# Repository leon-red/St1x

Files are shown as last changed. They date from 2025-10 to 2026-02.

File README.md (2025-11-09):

# St1x
 - S: STM32F103CBT6
 - T: T系列烙铁头
 - 1x: 12 & 13 & 16
### 基于SMT32F103自动调温烙铁, 使用T12 & T13 & T16 烙铁头实现
***
# 非常感谢以下开源的作者与项目
- 项目参考：[Eddddddddy](https://github.com/Eddddddddy/T12-PD-SolderingPen)
- AI编码助手：[北京引力弹弓科技有限公司](https://www.trae.cn/)
- OLED驱动： [U8G2](https://github.com/olikraus/u8g2) 库, 具体使用方法参考 [U8G2官方WiKi](https://github.com/olikraus/u8g2)
- 下载&调试工具： [PowerWriter PWLINK2](https://item.taobao.com/item.htm?id=675067753017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)
- 开发环境:
  - [Clion 2023.3.6](https://www.jetbrains.com/zh-cn/clion/download/other.html)
  - [STM32CulbMX6.15.0](https://www.st.com.cn/content/st_com/zh/stm32cubemx.html)
  - [openocd-v0.12.0-i686-w64-mingw32](https://github.com/openocd-org/openocd)
  - [mingw64-x86_64-13.2.0-release-win32-seh-msvcrt-rt_v11-rev1](https://sourceforge.net/projects/mingw-w64/files/mingw-w64/mingw-w64-release/)
  - [arm-gnu-toolchain-13.2.Rel1-mingw-w64-i686-arm-none-eabi](https://developer.arm.com/downloads/-/arm-gnu-toolchain-downloads)

- 使用`STM32CulbMX6.15.0`打开`St1x.ioc`, 点击`GENERATE CODE`生成初始化代码, 再使用`Clion 2023.3.6`编译下载。 有时间再配合图文讲解完善操作~~~~~~
***
# 功能实现结果
## 硬件设计
  - [x] 原理图设计
  - [x] PCB设计
  - [x] 硬件电路调试
    - [x] PD快充协议触发
    - [x] 系统供电
    - [x] 按键
    - [x] 烙铁头温度控制
    - [x] 屏幕升压供电
    - [x] 工作指示灯
    - [x] 蜂鸣器提示
    - [x] 烙铁头电动势运放电路
    - [x] 加速度传感器
    - [x] 屏幕显示
***
## 外观设计
- [x] ID设计
- [x] 外壳3D设计
***
## 软件设计
- [x] O-LED_U8G2 驱动(SPI)
- [x] 界面显示
- [x] 按键控制
- [x] PID算法
- [x] ADC温度读取
- [x] USB输入电压检测
- [x] 自动温度控制
- [x] 静置检测
- [x] 烙铁头温度校准
- [ ] RGB_LED指示
- [x] WS2812B_RGB指示
- [ ] 蜂鸣器事件
***
# 图片展示


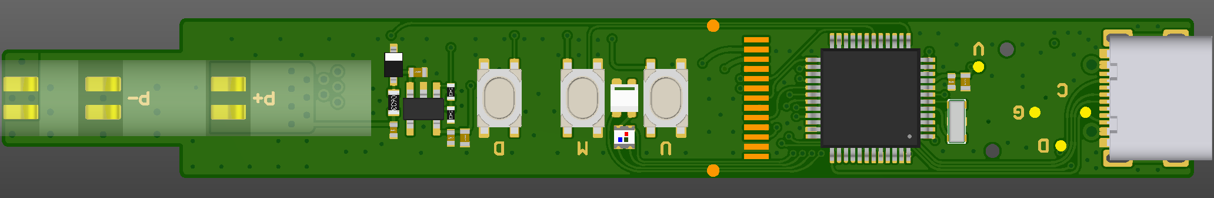
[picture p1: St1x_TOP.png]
St1x_TOP


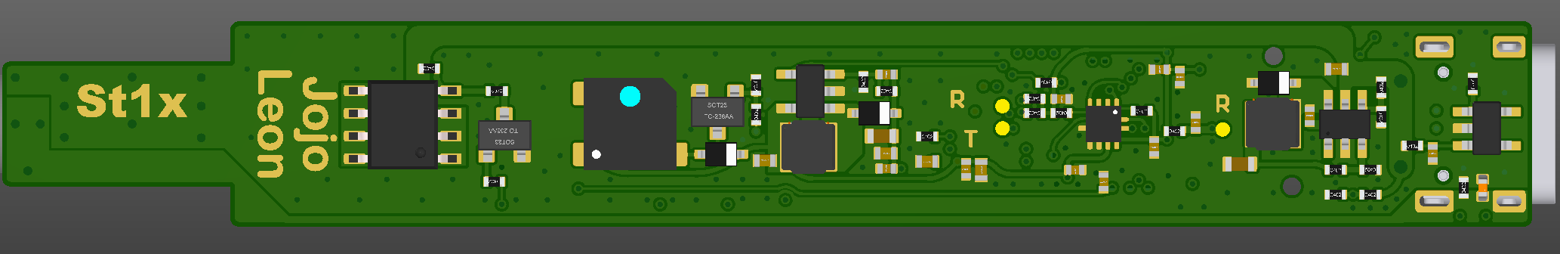
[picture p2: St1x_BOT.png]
St1x_BOT


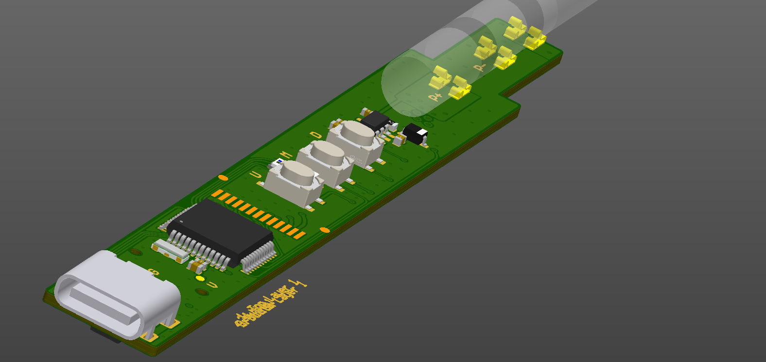
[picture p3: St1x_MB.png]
St1x_MB


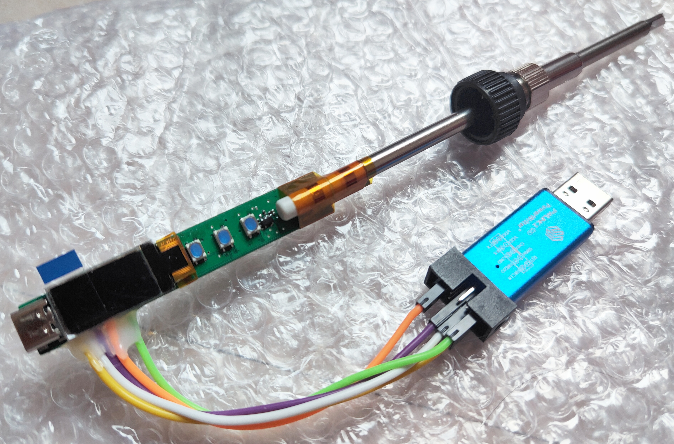
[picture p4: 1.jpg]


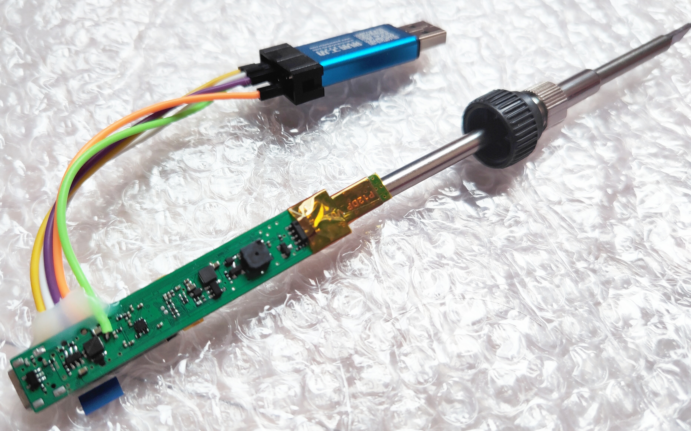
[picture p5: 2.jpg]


# 原理图
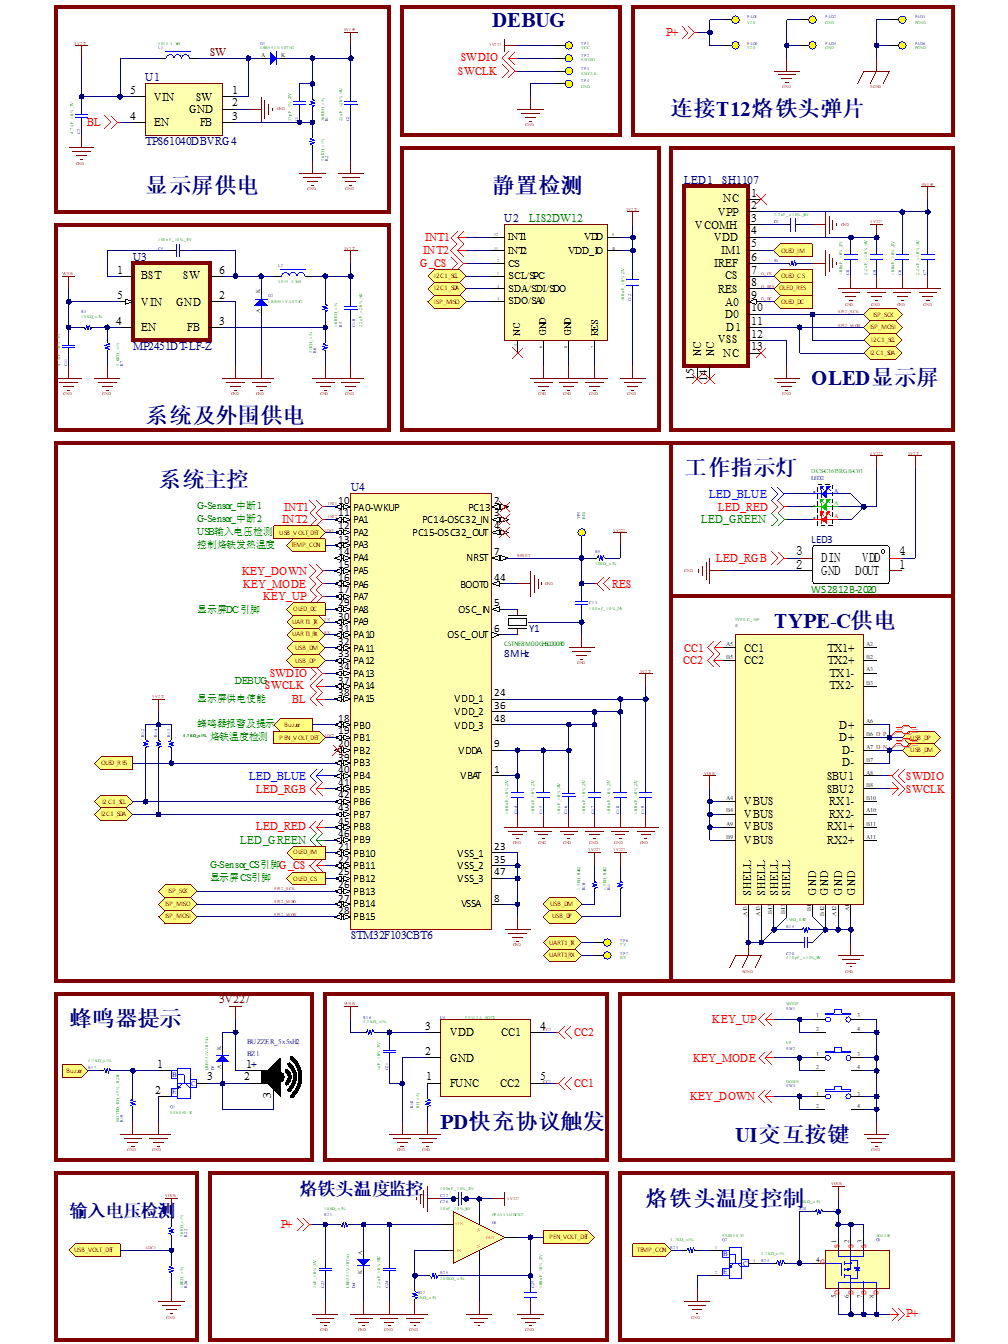
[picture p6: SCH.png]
SCH

[点击打开PDF原理图](HardwarDesign/SCH.pdf)

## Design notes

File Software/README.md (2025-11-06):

# St1x
 - S: STM32F103CBT6
 - T: T系列烙铁头
 - 1x: 12 & 13 & 16
### 基于SMT32F103自动调温烙铁, 使用T12 & T13 & T16 烙铁头实现
***
# 非常感谢以下开源的作者与项目
- 项目参考：[Eddddddddy](https://github.com/Eddddddddy/T12-PD-SolderingPen)
- AI编码助手：[北京引力弹弓科技有限公司](https://www.trae.cn/)
- OLED驱动： [U8G2](https://github.com/olikraus/u8g2) 库, 具体使用方法参考 [U8G2官方WiKi](https://github.com/olikraus/u8g2)
- 下载&调试工具： [PowerWriter PWLINK2](https://item.taobao.com/item.htm?id=675067753017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)
- 开发环境:
  - [Clion 2023.3.6](https://www.jetbrains.com/zh-cn/clion/download/other.html)
  - [STM32CulbMX6.15.0](https://www.st.com.cn/content/st_com/zh/stm32cubemx.html)
  - [openocd-v0.12.0-i686-w64-mingw32](https://github.com/openocd-org/openocd)
  - [mingw64-x86_64-13.2.0-release-win32-seh-msvcrt-rt_v11-rev1](https://sourceforge.net/projects/mingw-w64/files/mingw-w64/mingw-w64-release/)
  - [arm-gnu-toolchain-13.2.Rel1-mingw-w64-i686-arm-none-eabi](https://developer.arm.com/downloads/-/arm-gnu-toolchain-downloads)

- 使用`STM32CulbMX6.15.0`打开`St1x.ioc`, 点击`GENERATE CODE`生成初始化代码, 再使用`Clion 2023.3.6`编译下载。 有时间再配合图文讲解完善操作~~~~~~
***
# 功能实现结果
## 硬件设计
  - [x] 原理图设计
  - [x] PCB设计
  - [x] 硬件电路调试
    - [x] PD快充协议触发
    - [x] 系统供电
    - [x] 按键
    - [x] 烙铁头温度控制
    - [x] 屏幕升压供电
    - [x] 工作指示灯
    - [x] 蜂鸣器提示
    - [x] 烙铁头电动势运放电路
    - [x] 加速度传感器
    - [x] 屏幕显示
***
## 外观设计
- [x] ID设计
- [x] 外壳3D设计
***
## 软件设计
- [x] O-LED_U8G2 驱动(SPI)
- [x] 界面显示
- [x] 按键控制
- [x] PID算法
- [x] ADC温度读取
- [x] USB输入电压检测
- [x] 自动温度控制
- [ ] 静置检测
- [ ] RGB_LED指示
- [ ] WS2812B_RGB指示
- [ ] 蜂鸣器事件
***
# 图片展示














# 原理图
[SCH.pdf](..%2FHardwarDesign%2FSCH.pdf)

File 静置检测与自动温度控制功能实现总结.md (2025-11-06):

# 静置检测与自动温度控制功能实现总结

## 1. 项目目标

实现基于6轴传感器的静置检测功能，当设备静置一段时间后自动降低温度，再静置更长时间后停止加热。同时实现设备运动检测，自动恢复加热功能。

## 2. 功能实现过程

### 2.1 初始实现
- 在 [St1xStatic.c](file:///D:/Leon/OneDrive/Leon/St1x/Software/St1xDrivers/St1xStatic.c) 中实现基于LIS2DW12 6轴传感器的静置检测功能
- 设置默认参数：15分钟后降低温度至160°C，30分钟后停止加热
- 实现传感器数据读取、运动检测算法和温度控制逻辑

### 2.2 编译与链接问题修复
- 修复了函数声明和定义不匹配的问题
- 解决了静态函数访问权限问题
- 添加了必要的头文件包含和外部变量声明

### 2.3 调试信息显示
- 实现在OLED屏幕上显示调试信息，位置为X15, Y26
- 显示内容包括：加速度值、静置状态、加热状态和距离上次运动时间

### 2.4 算法优化
- 优化运动检测阈值，从300mg降低到150mg，提高检测灵敏度
- 改进传感器数据读取方式，确保每次检测都读取最新数据
- 解决时间计数器溢出问题，只在加热状态下进行静置检测

## 3. 遇到的主要问题及解决方案

### 3.1 传感器检测不灵敏
**问题**：设备无法正确进入静置状态，始终检测到运动
**解决方案**：
- 降低运动检测阈值从300mg到150mg
- 改进算法，区分传感器噪声和真实运动
- 添加误差阈值机制，过滤小幅数值跳变

### 3.2 时间计数问题
**问题**：静置时间无法正确累积，L值在0和1之间跳变
**解决方案**：
- 优化时间计算逻辑，避免因小幅跳变重置时间计数器
- 区分噪声阈值和运动检测阈值
- 确保时间累积的稳定性

### 3.3 加热控制问题
**问题**：达到设定时间后无法降低温度或停止加热
**解决方案**：
- 修复加热控制回调函数中的提前返回问题
- 确保温度设置在加热状态停止前完成
- 调整参数单位从分钟改为秒，提高调试效率

### 3.4 自动恢复问题
**问题**：设备停止加热后无法通过运动检测自动恢复
**解决方案**：
- 修改主循环调用逻辑，始终执行静置检测
- 区分自动停止和手动停止状态
- 实现手动停止标记机制，提升用户体验

## 4. 功能增强

### 4.1 手动/自动停止区分
- 添加手动停止标记，区分用户按键停止和自动停止
- 手动停止后不自动恢复加热，需要用户再次按键启动
- 自动停止后检测到运动可自动恢复加热

### 4.2 参数配置优化
- 提供默认参数配置函数，便于通过宏定义调整参数
- 统一时间单位为秒，提高调试效率
- 简化参数设置接口

### 4.3 调试信息优化
- 简化调试显示内容，只保留关键信息
- 确保调试信息与实际状态一致
- 停止加热后相关时间值归零，避免误导

## 5. 最终功能效果

1. **静置检测**：设备静置15分钟后自动降低温度至160°C，30分钟后停止加热
2. **运动检测**：设备运动时自动恢复加热状态
3. **状态区分**：自动停止后可自动恢复，手动停止后需手动启动
4. **调试显示**：在OLED屏幕指定位置显示关键状态信息
5. **安全保护**：防止用户初次上电时意外加热造成伤害

## 6. 技术要点总结

- 有效利用6轴传感器的三轴数据进行运动检测
- 实现噪声过滤算法，提高检测准确性
- 合理设计状态机，确保各状态转换正确
- 区分自动和手动操作，提升用户体验
- 优化资源使用，避免不必要的系统消耗

## 7. 经验教训

1. 传感器数据处理需要考虑噪声影响，不能直接使用原始数据
2. 时间计数逻辑需要仔细设计，避免因小幅波动影响计时准确性
3. 加热控制逻辑需要考虑回调函数的执行条件
4. 用户体验需要细致考虑，区分不同场景下的行为
5. 调试信息要准确反映系统状态，避免误导开发者或用户

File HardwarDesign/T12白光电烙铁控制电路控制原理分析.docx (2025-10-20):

# T12白光电烙铁控制电路控制原理分析

T12白光电烙铁，其烙铁头内部的加热丝与热电偶串联，两个引脚既是电源的输入线，也是热电偶信号的输出线。一般的控制电路的电路原理图一般如下:

## 电路的工作过程如下：

1、 电路中运放LM358的2脚预置了热电偶在设定的温度下的信号电压值(mV级的)，当电路上电时，LM358的3脚电压低于2脚，运放的输出端1脚输出低电平，二极管D3将另一个运放的6脚箝位为低电平，其输出端7脚会输出高电平。这个高电平经R9的电阻传递给三极管Q2，三极管将饱和，其集电极电位降低。两接到三极管C极的MOS管Q1的G极点位降低而使MOS管导通，电源经 D 极到S极开始为 T12 供电。
2、 电源为 T12 供电时，电源电压通过R5的电阻为电容器C5充电，短时间可使运放3脚的电平高于2脚，运放的1脚翻转为高电平。
3、 D3将1脚的高电平隔离，6 脚通过R7的电阻给C6的电容缓慢充电,延时到运放6脚电位高于5脚时,运放7脚输出低电平,三极管截止，Q1也截止，停止向T12供电。
4、 一旦Q1截止，停止向T12 供电。则LM358的3脚电压将迅速变为低电平。但是这个低电平实际上等于从T12 内部的热电偶通过R5的电阻传来的热电偶的信号电压。 如果此时热电偶的信号电压还低于预置的运放2脚电平,则电路状态将重复①的过程进行①→②→③→④的循环。 如果此时热电偶的信号电压已经高于预置的运放2脚电平，则意味着烙铁头温度已经达到预设值，LM358 将不会翻转，电路不会向 T12 供电。这个停电的过程一直等待运放3脚的电平再次降低到2脚的预置值以下,才开始再次翻转为T12供电。使烙铁头升温。这样的动作保持着 T12 烙铁头的恒温状态。
  a) 以上红色字体部分，是以前一般的分析资料没有明确说清楚的，它是这个控制电路能控制 T12白光温度的精髓所在。
  b) 总言之，控制电路是脉冲状态地为T12供电，脉冲宽度取决于运放5脚上R7的电阻给C6电容充电的速度。脉冲间隔很小，取决于运放3脚上C5电容器的电荷经R5的电阻再经T12的发热丝泄放的速度。在脉冲间隔期间，电路才真正检测热电偶的信号，确定脉冲供电是否应该继续进行，从而实现烙铁头的恒温。

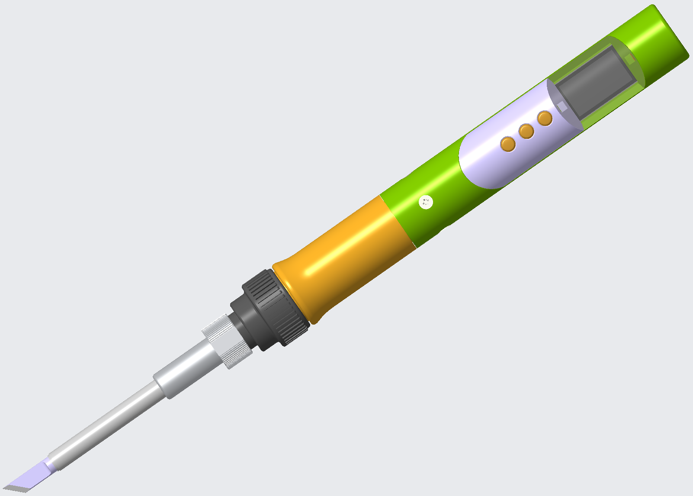
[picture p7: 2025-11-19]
HardwarDesign/Image/ST12.png

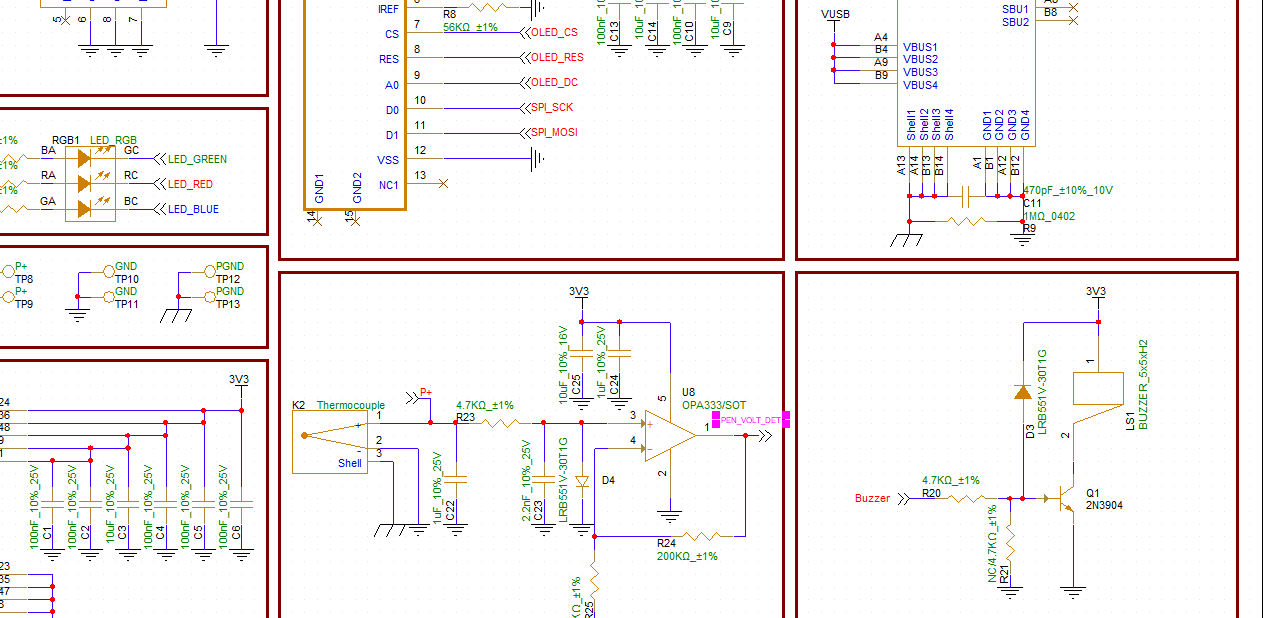
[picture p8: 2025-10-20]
HardwarDesign/Cadence/ST1X.png

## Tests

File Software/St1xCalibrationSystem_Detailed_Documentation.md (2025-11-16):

# ST1X 校准系统详细技术文档

## 1. 系统架构与设计原理

### 1.1 系统整体架构

```
┌─────────────────────────────────────────────────────────────┐
│                   主系统 (Main System)                       │
├─────────────────────────────────────────────────────────────┤
│  ┌─────────────────────────────────────────────────────┐    │
│  │             校准系统 (CalibrationSystem)            │    │
│  ├─────────────────────────────────────────────────────┤    │
│  │  ┌─────────────┐  ┌─────────────┐  ┌─────────────┐   │    │
│  │  │  状态管理   │  │  温度控制  │  │  界面显示   │   │    │
│  │  │  模块       │  │  模块      │  │  模块       │   │    │
│  │  └─────────────┘  └─────────────┘  └─────────────┘   │    │
│  │  ┌─────────────┐  ┌─────────────┐  ┌─────────────┐   │    │
│  │  │  按键处理   │  │  数据存储  │  │  电压检测   │   │    │
│  │  │  模块       │  │  模块      │  │  模块       │   │    │
│  │  └─────────────┘  └─────────────┘  └─────────────┘   │    │
│  └─────────────────────────────────────────────────────┘    │
├─────────────────────────────────────────────────────────────┤
│  ┌─────────────┐  ┌─────────────┐  ┌─────────────┐        │
│  │  PID控制    │  │  温度采集   │  │  OLED显示   │        │
│  │  系统       │  │  系统       │  │  系统       │        │
│  └─────────────┘  └─────────────┘  └─────────────┘        │
└─────────────────────────────────────────────────────────────┘
```

### 1.2 核心设计参数

**系统配置参数：**
```c
#define CALIBRATION_POINTS 9                    // 校准点数：9个
#define TEMPERATURE_TOLERANCE 5.0f              // 温度容差：±5°C
#define TEMPERATURE_STABLE_TIME 1000            // 温度稳定时间：1000ms
#define UPDATE_INTERVAL 20                       // 更新间隔：20ms
#define TEMPERATURE_ADJUST_STEP 1.0f            // 温度调整步进：1.0°C
#define KEY_DEBOUNCE_TIME 50                    // 按键去抖时间：50ms
#define CAL_KEY_LONG_PRESS_TIME 1000            // 按键长按时间：1000ms
#define LOW_VOLTAGE_DISPLAY_TIME 5000           // 电压不足显示时间：5000ms
```

**校准温度点定义：**
```c
static const float calibration_temperatures[CALIBRATION_POINTS] = {
    100.0f, 150.0f, 200.0f, 250.0f, 300.0f, 
    350.0f, 400.0f, 450.0f, 500.0f
};
```

### 1.3 数据结构设计

**校准点结构体：**
```c
typedef struct {
    uint8_t point_id;                    // 校准点ID（1-9）
    float target_temperature;           // 目标温度
    float adjusted_temperature;         // 调整后的目标温度
    float calibration_offset;           // 校准偏移量
    CalibrationPointState state;        // 当前状态
    uint32_t heating_start_time;       // 加热开始时间
    uint32_t stable_start_time;        // 稳定开始时间
    float max_temp_deviation;          // 最大温度偏差记录
    uint8_t heating_cycles;            // 加热循环次数
} CalibrationPoint;
```

**系统状态变量：**
```c
static CalibrationSystemState system_state = CAL_STATE_IDLE;
static CalibrationPoint calibration_points[CALIBRATION_POINTS];
static uint8_t current_point_index = 0;
static uint32_t last_update_time = 0;
static uint8_t save_result = 0;
static uint8_t low_voltage_state = 0;
static uint32_t low_voltage_start_time = 0;
```

## 2. 系统启动流程详细分析

### 2.1 系统初始化阶段

**调用入口：** `CalibrationSystem_Init()`

**初始化步骤：**
1. **状态变量重置**
   - `system_state = CAL_STATE_IDLE`
   - `current_point_index = 0`
   - `save_result = 0`
   - `last_update_time = 0`

2. **电压检测状态重置**
   - `low_voltage_state = 0`
   - `low_voltage_start_time = 0`

3. **校准点初始化**
   ```c
   for (int i = 0; i < CALIBRATION_POINTS; i++) {
       InitializeCalibrationPoint(i);
   }
   ```

4. **温度限制设置**
   - `calibration_temperature_limit = 500.0f`

**单个校准点初始化逻辑：**
```c
static void InitializeCalibrationPoint(uint8_t point_index) {
    CalibrationPoint* point = &calibration_points[point_index];
    
    point->point_id = point_index + 1;  // ID从1开始
    point->target_temperature = calibration_temperatures[point_index];
    point->adjusted_temperature = calibration_temperatures[point_index];
    point->calibration_offset = 0.0f;  // 初始偏移量为0
    point->state = CAL_POINT_WAITING;
    point->heating_start_time = 0;
    point->stable_start_time = 0;
    point->max_temp_deviation = 0.0f;
    point->heating_cycles = 0;
}
```

### 2.2 系统启动阶段

**调用入口：** `CalibrationSystem_Start()`

**启动条件检查：**
```c
if (system_state != CAL_STATE_IDLE) {
    return;  // 只有在空闲状态才能启动
}
```

**启动步骤详细分析：**

1. **第一个校准点设置**
   ```c
   if (CALIBRATION_POINTS > 0) {
       CalibrationPoint* first_point = &calibration_points[0];
       first_point->target_temperature = calibration_temperatures[0];
       first_point->adjusted_temperature = calibration_temperatures[0];
       
       // 设置PID目标温度
       SetPointTemperature(0, first_point->adjusted_temperature);
       
       // 显式设置目标温度变量
       extern float target_temperature;
       target_temperature = first_point->adjusted_temperature;
   }
   ```

2. **加热系统启动**
   ```c
   heating_status = 1;  // 设置加热状态为启用
   HAL_TIM_PWM_Start(&htim2, TIM_CHANNEL_2);  // 启动PWM输出
   startHeatingControlTimer();  // 启动PID控制器的定时器
   ```

3. **状态转换**
   ```c
   system_state = CAL_STATE_VOLTAGE_CHECK;
   low_voltage_start_time = HAL_GetTick();  // 记录电压检测开始时间
   ```

## 3. 电压检测阶段详细流程

### 3.1 电压检测状态处理

**处理函数：** `ProcessVoltageCheckState(uint32_t current_time)`

**检测逻辑：**
```c
// 检查电压是否足够
extern uint8_t isUSBVoltageSufficient(void);
if (isUSBVoltageSufficient()) {
    // 电压足够，进入校准运行状态
    // ... 详细处理逻辑
} else {
    // 电压不足，检查是否超过5秒显示时间
    if ((current_time - low_voltage_start_time) >= LOW_VOLTAGE_DISPLAY_TIME) {
        CalibrationSystem_Stop();  // 超过5秒，返回主界面
    }
}
```

**电压足够时的处理流程：**

1. **温度限制调整**
   ```c
   extern float max_temperature_limit;
   max_temperature_limit = 500.0f;  // 校准温度限制
   ```

2. **系统状态重置**
   ```c
   current_point_index = 0;
   save_result = 0;
   system_state = CAL_STATE_RUNNING;
   ```

3. **校准点重新初始化**
   ```c
   for (int i = 0; i < CALIBRATION_POINTS; i++) {
       InitializeCalibrationPoint(i);
   }
   ```

4. **第一个校准点启动**
   ```c
   SetPointTemperature(0, calibration_points[0].adjusted_temperature);
   calibration_points[0].state = CAL_POINT_HEATING;
   calibration_points[0].heating_start_time = current_time;
   calibration_points[0].heating_cycles = 1;
   
   // 立即将校准点温度写入目标温度变量
   extern float target_temperature;
   target_temperature = calibration_points[0].adjusted_temperature;
   ```

### 3.2 电压检测状态下的按键处理

**处理函数：** `HandleVoltageCheckKey(KeyType key)`

**按键响应逻辑：**

1. **MODE短按（确认电压正常）**
   ```c
   if (key == KEY_MODE) {
       system_state = CAL_STATE_RUNNING;
       current_point_index = 0;
       SetPointTemperature(current_point_index, calibration_points[current_point_index].adjusted_temperature);
       extern float target_temperature;
       target_temperature = calibration_points[current_point_index].adjusted_temperature;
       calibration_points[current_point_index].state = CAL_POINT_HEATING;
   }
   ```

2. **MODE长按（跳过电压检测）**
   ```c
   else if (key == KEY_MODE_LONG) {
       system_state = CAL_STATE_RUNNING;
       // ... 与短按相同的处理逻辑
   }
   ```

## 4. 校准运行阶段详细分析

### 4.1 系统更新循环

**主更新函数：** `CalibrationSystem_Update(u8g2_t *u8g2)`

**更新频率控制：**
```c
uint32_t current_time = HAL_GetTick();
if ((current_time - last_update_time) < UPDATE_INTERVAL) {
    return;  // 20ms间隔控制
}
last_update_time = current_time;
```

**更新流程：**
1. **按键扫描**
   ```c
   KeyType key = CalibrationKey_Scan();
   if (key != KEY_NONE) {
       CalibrationSystem_HandleKey(key);
   }
   ```

2. **状态处理**
   ```c
   switch (system_state) {
       case CAL_STATE_VOLTAGE_CHECK:
           ProcessVoltageCheckState(current_time);
           break;
       case CAL_STATE_RUNNING:
           ProcessCalibrationPoint(current_point_index);
           break;
       default:
           break;
   }
   ```

3. **界面绘制**
   ```c
   DrawCalibrationInterface(u8g2, current_point_index);
   ```

### 4.2 单个校准点处理状态机

**处理函数：** `ProcessCalibrationPoint(uint8_t point_index)`

#### 4.2.1 加热阶段 (CAL_POINT_HEATING)

**温度稳定性判断逻辑：**
```c
float current_temp = filtered_temperature;
float target_temp = point->adjusted_temperature;
float temp_diff = fabs(current_temp - target_temp);

// 记录最大温度偏差
if (temp_diff > point->max_temp_deviation) {
    point->max_temp_deviation = temp_diff;
}

// 检查温度是否稳定
if (temp_diff <= TEMPERATURE_TOLERANCE) {
    if (point->stable_start_time == 0) {
        point->stable_start_time = current_time;
    } else if ((current_time - point->stable_start_time) >= TEMPERATURE_STABLE_TIME) {
        point->state = CAL_POINT_STABLE;  // 进入稳定状态
    }
} else {
    point->stable_start_time = 0;  // 温度不稳定，重置计时器
}
```

#### 4.2.2 稳定阶段 (CAL_POINT_STABLE)

**按键处理逻辑：** `HandleRunningStateKey(KeyType key)`

**UP按键处理：**
```c
if (key == KEY_UP) {
    // 增加偏移量（补偿负偏差）
    point->calibration_offset += TEMPERATURE_ADJUST_STEP;
    
    // 重新计算调整后的目标温度
    point->adjusted_temperature = point->target_temperature + point->calibration_offset;
    
    // 温度上限保护
    if (point->adjusted_temperature > calibration_temperature_limit) {
        point->adjusted_temperature = calibration_temperature_limit;
        point->calibration_offset = point->adjusted_temperature - point->target_temperature;
    }
    
    // 更新PID目标温度
    setT12Temperature(point->adjusted_temperature);
}
```

**DOWN按键处理：**
```c
else if (key == KEY_DOWN) {
    // 减少偏移量（补偿正偏差）
    point->calibration_offset -= TEMPERATURE_ADJUST_STEP;
    
    // 重新计算调整后的目标温度
    point->adjusted_temperature = point->target_temperature + point->calibration_offset;
    
    // 温度下限保护
    if (point->adjusted_temperature < 0.0f) {
        point->adjusted_temperature = 0.0f;
        point->calibration_offset = point->adjusted_temperature - point->target_temperature;
    }
    
    // 更新PID目标温度
    setT12Temperature(point->adjusted_temperature);
}
```

#### 4.2.3 调整完成阶段 (CAL_POINT_ADJUSTED)

**校准点完成处理：** `HandleCalibrationPointCompleted(uint8_t point_index)`

**完成逻辑：**
```c
// 如果是最后一个校准点，完成整个校准过程
if (point_index == (CALIBRATION_POINTS - 1)) {
    system_state = CAL_STATE_COMPLETE;
} else {
    // 切换到下一个校准点
    current_point_index++;
    CalibrationPoint* next_point = &calibration_points[current_point_index];
    
    // 设置下一个校准点的目标温度
    SetPointTemperature(current_point_index, next_point->target_temperature + next_point->calibration_offset);
    
    // 显式设置目标温度变量
    extern float target_temperature;
    target_temperature = next_point->target_temperature + next_point->calibration_offset;
    
    // 重置下一个校准点的状态
    next_point->state = CAL_POINT_HEATING;
    next_point->stable_start_time = 0;
}
```

## 5. 界面显示系统详细分析

### 5.1 界面绘制函数

**主绘制函数：** `DrawCalibrationInterface(u8g2_t *u8g2, uint8_t point_index)`

**绘制流程：**
1. **缓冲区清空**
   ```c
   u8g2_ClearBuffer(u8g2);
   ```

2. **电压检测**
   ```c
   if (!isUSBVoltageSufficient()) {
       // 显示电压不足提示
       u8g2_SetFont(u8g2, u8g2_font_6x10_tf);
       u8g2_DrawStr(u8g2, 0, 20, "Low Voltage!");
       u8g2_DrawStr(u8g2, 0, 32, "Cannot calibrate");
       u8g2_SendBuffer(u8g2);
       
       // 检查是否达到显示时间
       if ((HAL_GetTick() - low_voltage_start_time) >= LOW_VOLTAGE_DISPLAY_TIME) {
           CalibrationSystem_Stop();
           low_voltage_state = 0;
       }
       return;
   }
   ```

3. **状态相关界面绘制**
   - 电压检测状态界面
   - 运行状态界面
   - 完成状态界面

### 5.2 状态文本获取

**状态文本函数：** `GetPointStateText(CalibrationPointState state)`
```c
static const char* GetPointStateText(CalibrationPointState state) {
    switch (state) {
        case CAL_POINT_WAITING:  return "Waiting";
        case CAL_POINT_HEATING:  return "Heating...";
        case CAL_POINT_STABLE:   return "Stable";
        case CAL_POINT_ADJUSTED: return "Confirmed";
        default: return "Unknown";
    }
}
```

**帮助文本函数：** `GetPointHelpText(CalibrationPointState state)`
```c
static const char* GetPointHelpText(CalibrationPointState state) {
    switch (state) {
        case CAL_POINT_HEATING:  return "Heating...Wait";
        case CAL_POINT_STABLE:   return "UP/DN:Adj MODE:OK";
        case CAL_POINT_ADJUSTED: return "Completed";
        default: return "";
    }
}
```

## 6. 系统退出流程详细分析

### 6.1 正常退出流程

**停止函数：** `CalibrationSystem_Stop()`

**退出条件检查：**
```c
if (system_state == CAL_STATE_IDLE) {
    return;  // 只有在非空闲状态才能停止
}
```

**退出步骤：**

1. **停止加热控制**
   ```c
   stopHeatingControlTimer();  // 停止PID控制器的定时器
   HAL_TIM_PWM_Stop(&htim2, TIM_CHANNEL_2);  // 停止PWM输出
   ```

2. **重置加热状态**
   ```c
   heating_status = 0;
   ```

3. **恢复温度限制**
   ```c
   extern float max_temperature_limit;
   max_temperature_limit = 460.0f;  // 正常温度限制
   ```

4. **系统状态重置**
   ```c
   system_state = CAL_STATE_IDLE;
   current_point_index = 0;
   save_result = 0;
   ```

5. **电压状态重置**
   ```c
   low_voltage_state = 0;
   ```

### 6.2 异常退出处理

**异常退出场景：**
1. 用户长按MODE键强制退出
2. 电压不足超时自动退出
3. 系统错误导致的异常退出

**安全保护措施：**
- 立即停止加热，防止温度失控
- 恢复原始温度设置
- 清理系统状态，确保安全退出

## 7. 模块间交互详细分析

### 7.1 与PID控制器的交互

**外部变量声明：**
```c
extern void setT12Temperature(float temperature);
extern void startHeatingControlTimer(void);
extern void stopHeatingControlTimer(void);
extern float target_temperature;
extern uint8_t heating_status;
extern uint8_t heating_control_enabled;
extern TIM_HandleTypeDef htim2;
```

**温度设置函数：** `SetPointTemperature(uint8_t point_index, float temperature)`

**交互流程：**
```c
// 设置PID目标温度
setT12Temperature(temperature);

// 启动/停止控制定时器
startHeatingControlTimer();
stopHeatingControlTimer();
```

### 7.2 与温度采集模块的交互

**温度数据获取：**
```c
extern float filtered_temperature;
float current_temp = filtered_temperature;
```

**数据流路径：**
```
ADC温度采集 → 滤波处理 → filtered_temperature → 校准系统温度监控
```

### 7.3 与显示系统的交互

**显示控制：**
```c
// 使用u8g2库进行OLED显示
u8g2_ClearBuffer(u8g2);
u8g2_SetFont(u8g2, u8g2_font_6x10_tf);
u8g2_DrawStr(u8g2, x, y, text);
u8g2_SendBuffer(u8g2);
```

### 7.4 与按键系统的交互

**按键扫描：** `CalibrationKey_Scan()`

**按键类型定义：**
```c
typedef enum {
    KEY_NONE,
    KEY_UP,
    KEY_DOWN, 
    KEY_MODE,
    KEY_MODE_LONG
} KeyType;
```

## 8. 系统运行状态机详细分析

### 8.1 系统状态定义

**系统状态枚举：**
```c
typedef enum {
    CAL_STATE_IDLE,           // 空闲状态
    CAL_STATE_VOLTAGE_CHECK,  // 电压检测状态
    CAL_STATE_RUNNING,        // 运行状态
    CAL_STATE_COMPLETE        // 完成状态
} CalibrationSystemState;
```

**校准点状态枚举：**
```c
typedef enum {
    CAL_POINT_WAITING,   // 等待状态
    CAL_POINT_HEATING,   // 加热状态
    CAL_POINT_STABLE,    // 稳定状态
    CAL_POINT_ADJUSTED   // 调整完成状态
} CalibrationPointState;
```

### 8.2 状态转换详细流程

**完整状态转换图：**

```
[主系统] → [CAL_STATE_IDLE]
    ↓ (用户选择校准)
[CAL_STATE_VOLTAGE_CHECK]
    ├── 电压足够 → [CAL_STATE_RUNNING]
    ├── 电压不足超时 → [CAL_STATE_IDLE] 
    └── 用户按键跳过 → [CAL_STATE_RUNNING]
        ↓
[CAL_STATE_RUNNING]
    ├── 处理校准点1-9
    │   ├── CAL_POINT_WAITING → CAL_POINT_HEATING
    │   ├── CAL_POINT_HEATING → CAL_POINT_STABLE
    │   ├── CAL_POINT_STABLE → CAL_POINT_ADJUSTED
    │   └── CAL_POINT_ADJUSTED → 下一个点或完成
    ├── 用户强制退出 → [CAL_STATE_IDLE]
    └── 所有点完成 → [CAL_STATE_COMPLETE]
        ↓
[CAL_STATE_COMPLETE] → [CAL_STATE_IDLE]
```

### 8.3 状态转换条件详细说明

**IDLE → VOLTAGE_CHECK：**
- 条件：用户选择校准功能
- 动作：启动加热系统，开始电压检测

**VOLTAGE_CHECK → RUNNING：**
- 条件1：电压检测通过
- 条件2：用户按键跳过电压检测
- 动作：初始化校准点，开始第一个点加热

**RUNNING状态内部转换：**
- 加热 → 稳定：温度在容差范围内保持1000ms
- 稳定 → 调整完成：用户确认调整
- 调整完成 → 下一个点：自动切换到下一个校准点

**RUNNING → COMPLETE：**
- 条件：第9个校准点调整完成
- 动作：**立即停止加热** → 保存数据 → 设置完成状态

**任何状态 → IDLE：**
- 条件：用户强制退出或系统异常
- 动作：安全停止加热，恢复系统设置

## 9. 错误处理与安全机制

### 9.1 电压检测安全机制

**检测频率：** 每20ms检测一次
**超时保护：** 5秒自动退出
**用户干预：** 支持按键跳过检测

### 9.2 温度保护机制

**温度范围限制：** 0-500°C
**实时监控：** 持续监测温度偏差
**异常处理：** 超温立即停止加热

### 9.3 校准完成自动停止加热机制

**安全改进背景：**
- **问题：** 原系统在校准完成进入保存界面时，加热器仍继续工作
- **风险：** 可能导致过热和长时间运行的安全隐患
- **改进：** 在校准完成时立即自动停止加热

**实现机制：**
```c
// 在HandleCalibrationPointCompleted函数中，最后一个校准点完成时
if (point_index == (CALIBRATION_POINTS - 1)) {
    // 校准完成，立即停止加热以确保安全
    stopHeatingControlTimer();  // 停止PID控制器的定时器
    HAL_TIM_PWM_Stop(&htim2, TIM_CHANNEL_2);  // 停止PWM输出
    heating_status = 0;  // 禁用加热状态
    
    // 保存校准数据
    SaveCalibrationData();
    
    // 设置完成状态
    system_state = CAL_STATE_COMPLETE;
    
    // 调试信息输出
    #ifdef CALIBRATION_DEBUG_ENABLED
    printf("校准完成，加热已停止，数据已保存\\n");
    #endif
}
```

**安全优势：**
- **防止过热：** 校准完成后立即停止加热，避免温度失控
- **节能安全：** 减少不必要的能耗和加热器磨损
- **用户体验：** 用户无需手动停止加热，操作更安全便捷

### 9.4 系统状态一致性保护

**状态检查：** 每次状态转换前检查当前状态
**资源管理：** 确保加热器正确启动/停止
**数据完整性：** 校准数据正确保存

## 10. 性能优化与资源使用分析

### 10.1 内存使用优化

**静态内存分配：**
- 校准点数组：9个结构体，固定大小
- 状态变量：最小化全局变量使用
- 临时变量：栈上分配，自动回收

**内存占用分析：**
```c
// CalibrationPoint结构体大小估算
sizeof(CalibrationPoint) ≈ 4 + 4 + 4 + 4 + 4 + 4 + 4 + 1 ≈ 29字节
总内存占用：9 × 29 ≈ 261字节
```

### 10.2 CPU使用优化

**更新频率控制：** 20ms间隔，避免过度占用CPU
**计算优化：** 使用整数运算替代浮点运算
**状态机优化：** 最小化状态转换开销

### 10.3 实时性保障

**关键路径优化：**
- 温度采集响应时间：< 1ms
- 控制算法执行：< 5ms  
- 界面刷新：20ms间隔

## 11. 扩展性与维护性分析

### 11.1 系统扩展性

**校准点扩展：** 修改`CALIBRATION_POINTS`宏定义
**温度范围扩展：** 调整温度数组和限制值
**功能扩展：** 模块化设计支持功能添加

### 11.2 代码维护性

**模块化设计：** 功能分离，职责明确
**注释完善：** 关键函数和逻辑都有详细注释
**配置集中：** 所有参数在文件头部集中定义

### 11.3 调试支持

**调试开关：** `CALIBRATION_DEBUG_ENABLED`
**状态显示：** 实时显示系统状态和温度信息
**错误日志：** 支持错误状态记录和显示

---

## 12. 重要更新记录

### 12.1 安全改进更新（2024年）

**改进内容：** 校准完成自动停止加热机制
- **问题修复：** 解决校准完成进入保存界面时加热器继续工作的安全隐患
- **实现方式：** 在`HandleCalibrationPointCompleted`函数中添加完整的加热停止逻辑
- **安全优势：** 防止过热、节能安全、优化用户体验

**关键代码修改：**
```c
// 停止PID控制器的定时器
stopHeatingControlTimer();

// 停止PWM输出
HAL_TIM_PWM_Stop(&htim2, TIM_CHANNEL_2);

// 禁用加热状态
heating_status = 0;
```

**外部声明补充：**
```c
extern TIM_HandleTypeDef htim2;  // 添加htim2外部声明
```

### 12.2 系统变量完善

**新增系统变量：**
```c
static uint8_t low_voltage_state = 0;        // 电压检测状态
static uint32_t low_voltage_start_time = 0;  // 电压检测开始时间
```

---

**文档版本：** v1.1  
**最后更新：** 2024年（安全改进更新）  
**适用系统：** ST1X焊接台校准系统  
**代码文件：** `St1xCalibrationSystem.c`

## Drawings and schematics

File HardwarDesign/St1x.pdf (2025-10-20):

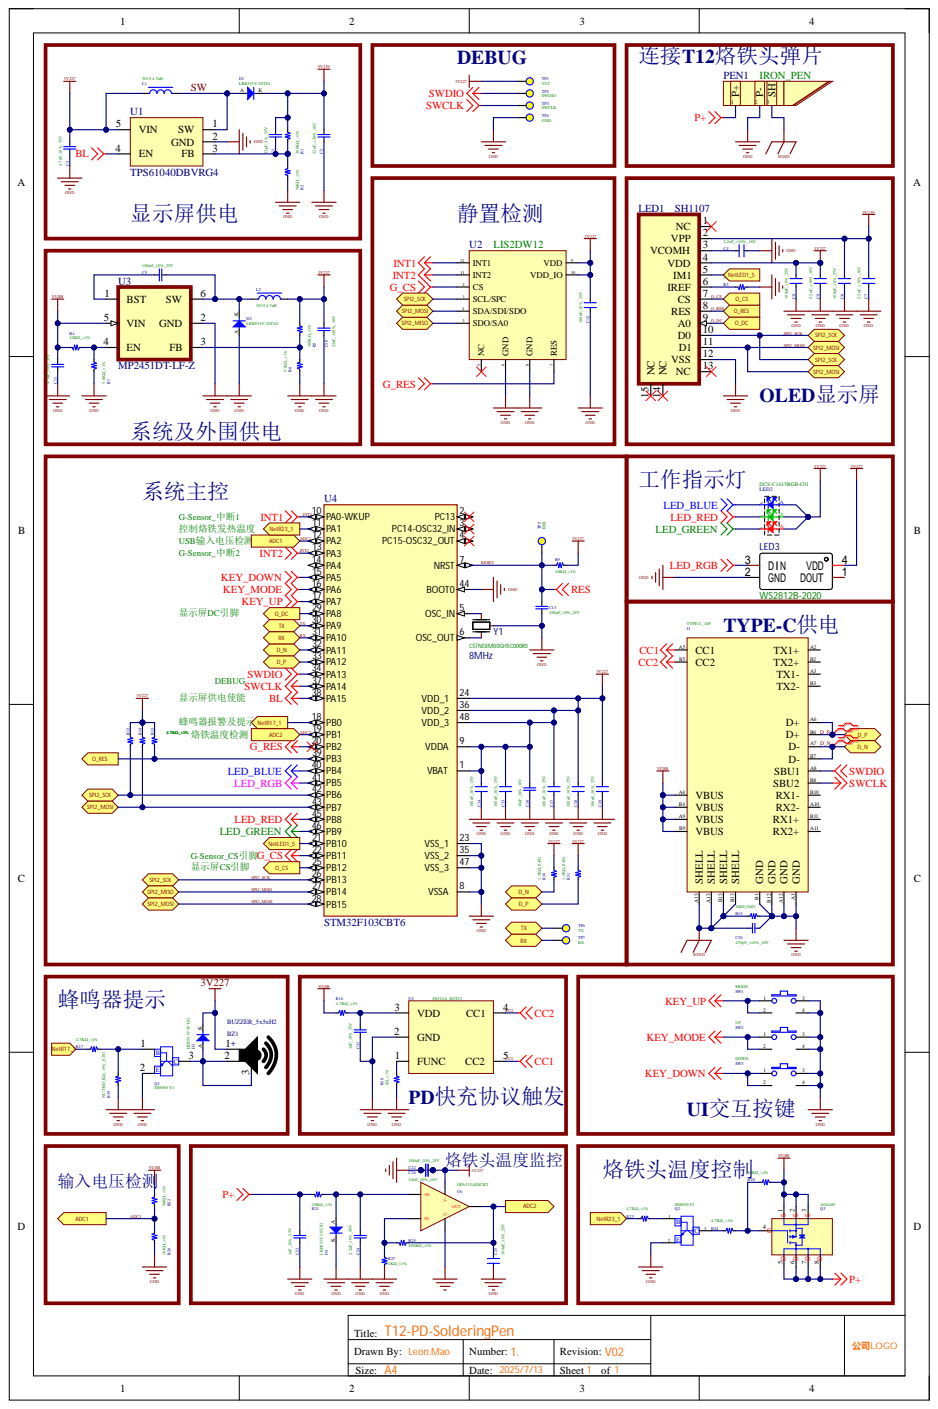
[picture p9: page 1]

T12-PD-SolderingPen Title: | | 公司LOGO
Drawn By: Leon.Mao | Number: 1. V02 | Revision:

Size: A4 | Date: 2025/7/13 | Sheet 1 1 of

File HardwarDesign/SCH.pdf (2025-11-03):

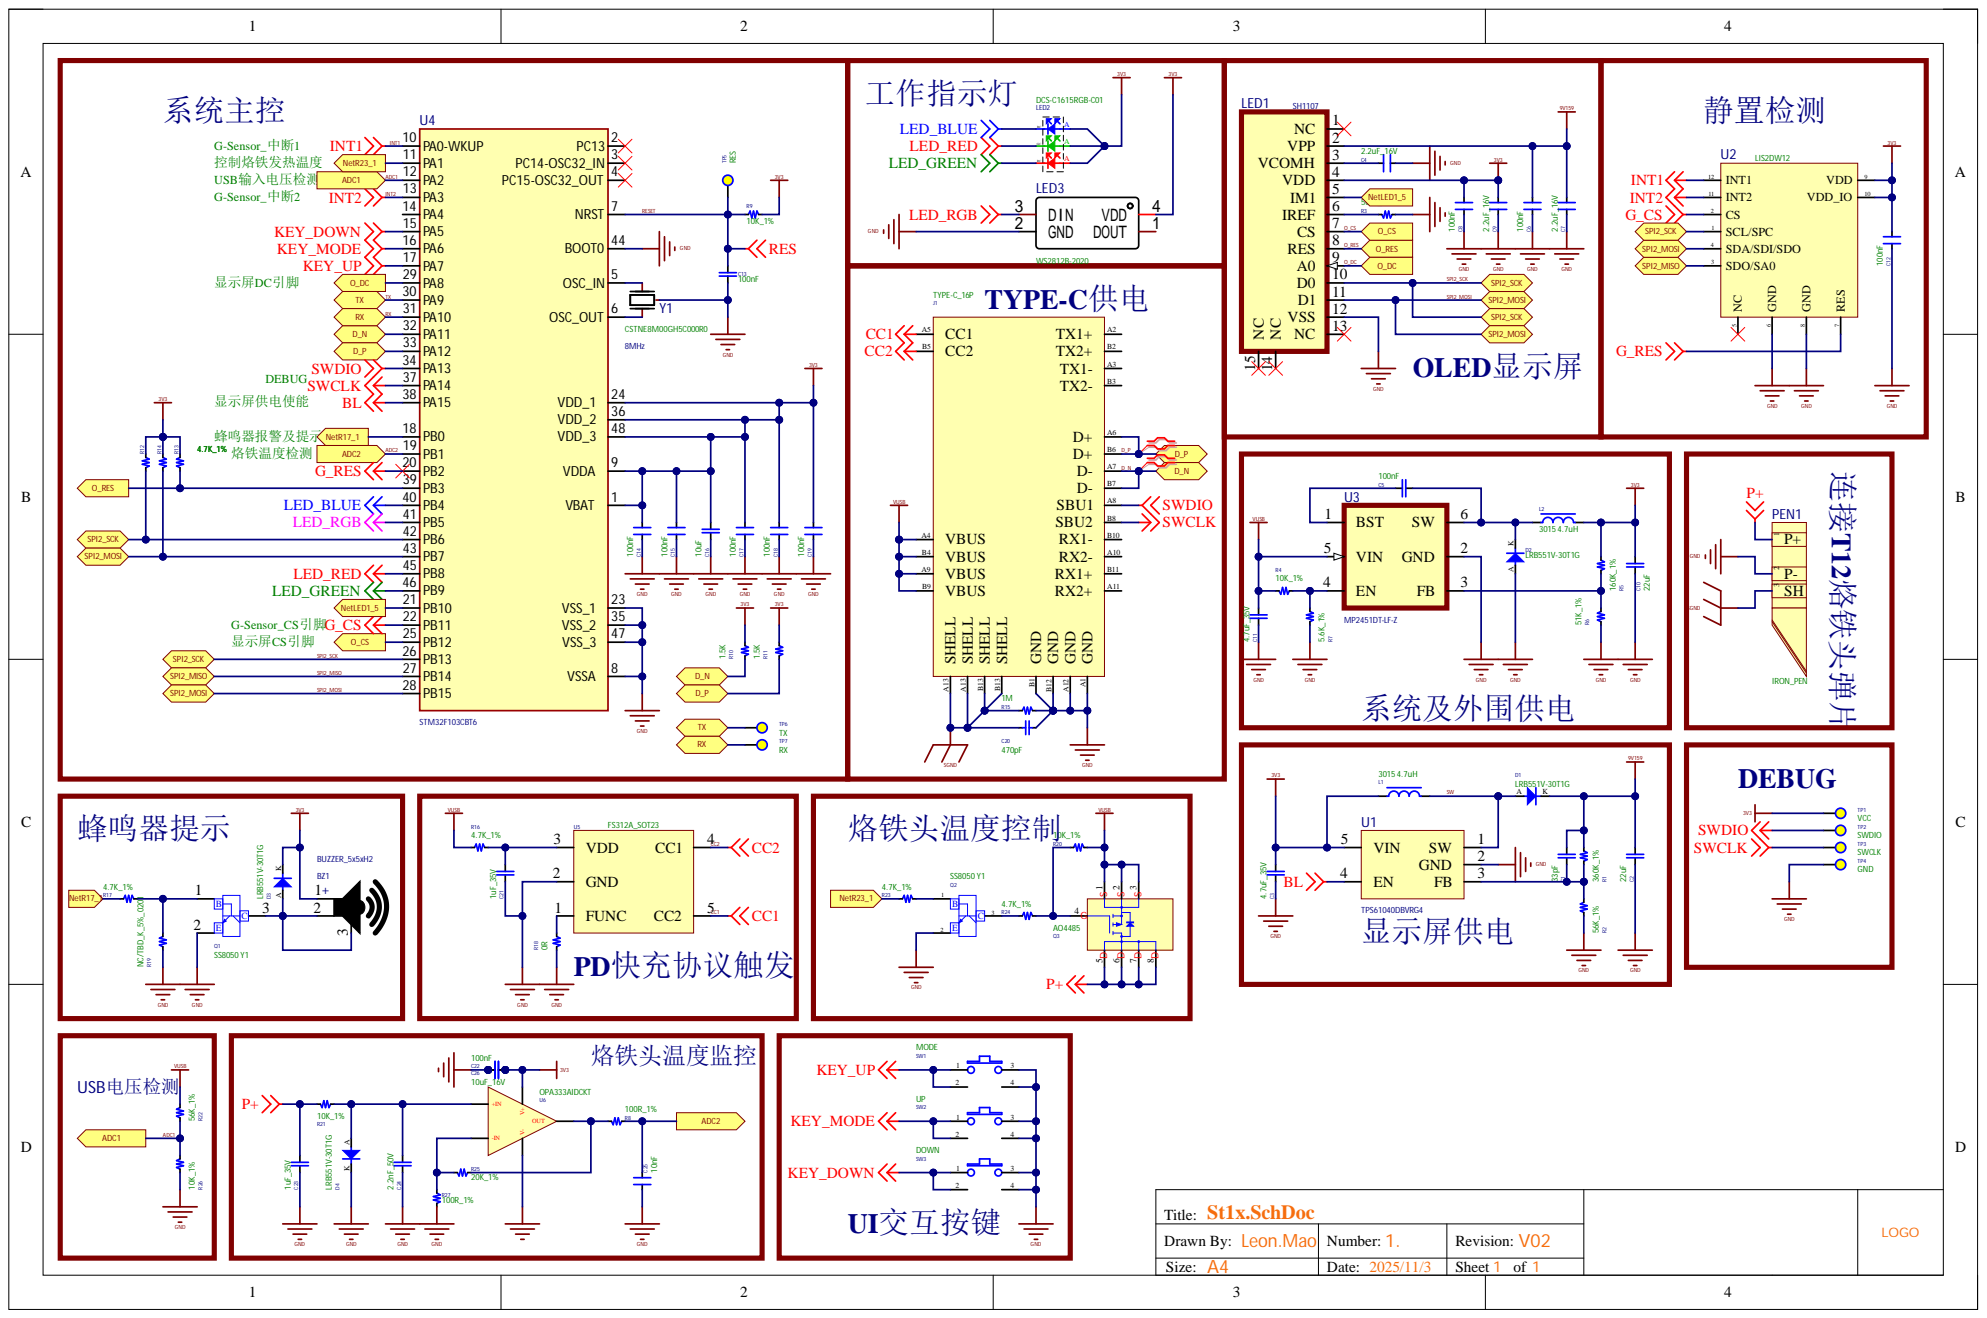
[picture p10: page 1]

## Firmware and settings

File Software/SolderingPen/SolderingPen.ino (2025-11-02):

// 烙铁笔控制程序
//
// 基于ATmega328控制的烙铁笔，适用于Hakko T12烙铁头
//
// 本版本代码实现的功能：
// - 烙铁头温度测量
// - 加热器的直接控制或PID控制
// - 通过按钮进行温度控制
// - 短按第一个按钮进入增强模式
// - 长按第一个按钮进入设置菜单
// - 通过陀螺仪检测手柄移动
// - 烙铁未连接检测（通过识别无效温度读数）
// - 如果烙铁未使用（移动检测）则进入定时休眠/关机模式
// - 测量输入电压、Vcc和ATmega内部温度
// - 在OLED上显示信息
// - 蜂鸣器提示
// - 校准和管理不同的烙铁头
// - 将用户设置存储到EEPROM中
// - 烙铁头更换检测
// - 可使用N沟道或P沟道MOSFET
//
// 电源应在6V至20V范围内。支持PD、QC和其他快速充电协议。
//
// 校准需要烙铁头温度计。为获得最佳效果，请在打开烙铁站后至少等待三分钟再开始校准过程。
//
// 控制器：ATmega328p
// 核心：Barebones ATmega (https://github.com/carlosefr/atmega)
// 时钟速度：16 MHz外部晶振
//
// 建议不要使用引导加载程序！
//
// 感谢代码贡献者：
// - John Glavinos, https://youtu.be/4YDcWfOQmz4
// - createskyblue, https://github.com/createskyblue
// - TaaraLabs, https://github.com/TaaraLabs
// - wagiminator, https://github.com/wagiminator



// 库文件包含
#include <U8g2lib.h>             // OLED显示库：https://github.com/olikraus/u8g2

#ifdef U8X8_HAVE_HW_SPI
#include <SPI.h>
#endif
#ifdef U8X8_HAVE_HW_I2C
#include <Wire.h>
#endif

#include <PID_v1.h>             // PID控制库：https://github.com/wagiminator/ATmega-Soldering-Station/blob/master/software/libraries/Arduino-PID-Library.zip
// (旧版cpp版本：https://github.com/mblythe86/C-PID-Library/tree/master/PID_v1)
#include <EEPROM.h>             // 用于将用户设置存储到EEPROM中
#include <avr/sleep.h>          // 用于ADC采样期间进入睡眠模式

#include "LIS2DW12Sensor.h"

// 固件版本号
#define VERSION       "v1.5"

// MOSFET类型定义
#define P_MOSFET                // P沟道MOSFET或N沟道MOSFET

// OLED控制器类型
#define SH1107                 // SH1107 OLED控制器
typedef u8g2_uint_t u8g_uint_t;

// 旋转编码器类型
#define ROTARY_TYPE   0         // 0: 每步2个增量；1: 每步4个增量（默认）
#define BUTTON_DELAY  5

// 引脚定义
#define SENSOR_PIN    A0        // 烙铁头温度传感器引脚
#define VIN_PIN       A1        // 输入电压检测引脚
#define BUZZER_PIN     5        // 蜂鸣器引脚
#define BUTTON_PIN     6        // 旋转编码器开关引脚
#define BUTTON_P_PIN   7        // 旋转编码器引脚1
#define BUTTON_N_PIN   8        // 旋转编码器引脚2
#define CONTROL_PIN    9        // 加热器MOSFET PWM控制引脚
#define SWITCH_PIN    10        // 手柄振动开关引脚

// 默认温度控制值（推荐焊接温度：300-380°C）
#define TEMP_MIN      150       // 最小可选温度
#define TEMP_MAX      400       // 最大可选温度
#define TEMP_DEFAULT  320       // 默认启动设定点温度
#define TEMP_SLEEP    150       // 休眠模式温度
#define TEMP_BOOST     50       // 增强模式温度增加值
#define TEMP_STEP      10       // 旋转编码器温度变化步长

// 默认烙铁头温度校准值
#define TEMP200       216       // ADC值为200时的温度
#define TEMP280       308       // ADC值为280时的温度
#define TEMP360       390       // ADC值为360时的温度
#define TEMPCHP       30        // 校准时芯片温度
#define TIPMAX        8         // 最大烙铁头数量
#define TIPNAMELENGTH 6         // 烙铁头名称最大长度（包括终止符）
#define TIPNAME       "BC1.5"   // 默认烙铁头名称

// 默认定时器值（0 = 禁用）
#define TIME2SLEEP    30        // 进入休眠模式的时间（分钟）
#define TIME2OFF       5        // 关闭加热器的时间（分钟）
#define TIMEOFBOOST   40        // 保持在增强模式的时间（秒）
#define LISTHRESHOLD  15        // LIS传感器阈值

// 控制参数
#define TIME2SETTLE   950       // 运放输出稳定时间（微秒）
#define SMOOTHIE      0.05      // 运放输出平滑因子（1=不平滑；0.05默认）
#define PID_ENABLE    false     // 启用PID控制
#define BEEP_ENABLE   true      // 启用/禁用蜂鸣器
#define MAINSCREEN    1         // 主屏幕类型（0: 大数字显示；1: 更多信息显示）

// EEPROM标识符
#define EEPROM_IDENT  0xE76C   // 用于识别EEPROM是否由本程序写入

// MOSFET控制定义
#if defined (P_MOSFET)         // P沟道MOSFET
#define HEATER_ON   255
#define HEATER_OFF  0
#define HEATER_PWM  255 - Output
#elif defined (N_MOSFET)       // N沟道MOSFET
#define HEATER_ON   0
#define HEATER_OFF  255
#define HEATER_PWM  Output
#else
#error 错误的MOSFET类型！
#endif

// 定义激进和保守的PID调谐参数
double aggKp = 11, aggKi = 0.5, aggKd = 1;
double consKp = 11, consKi = 3, consKd = 5;

// 可由用户更改并存储在EEPROM中的默认值
uint16_t  DefaultTemp   = TEMP_DEFAULT;
uint16_t  SleepTemp     = TEMP_SLEEP;
uint8_t   BoostTemp     = TEMP_BOOST;
uint8_t   time2sleep    = TIME2SLEEP;
uint8_t   time2off      = TIME2OFF;
uint8_t   timeOfBoost   = TIMEOFBOOST;
uint8_t   MainScrType   = MAINSCREEN;
bool      PIDenable     = PID_ENABLE;
bool      beepEnable    = BEEP_ENABLE;
uint8_t   LISthreshold  = LISTHRESHOLD;

// 烙铁头的默认值
uint16_t  CalTemp[TIPMAX][4] = {TEMP200, TEMP280, TEMP360, TEMPCHP};
char      TipName[TIPMAX][TIPNAMELENGTH] = {TIPNAME};
uint8_t   CurrentTip   = 0;
uint8_t   NumberOfTips = 1;

// 菜单项定义
const char *SetupItems[]       = { "设置菜单", "烙铁头设置", "温度设置",
                                   "定时器设置", "控制类型", "主屏幕",
                                   "蜂鸣器", "信息", "返回"
                                 };
const char *TipItems[]         = { "烙铁头:", "更换烙铁头", "校准烙铁头",
                                   "重命名烙铁头", "删除烙铁头", "添加新烙铁头", "返回"
                                 };
const char *TempItems[]        = { "温度设置", "默认温度", "休眠温度",
                                   "增强温度", "返回"
                                 };
const char *TimerItems[]       = { "定时器设置", "休眠定时器", "关机定时器",
                                   "增强定时器", "IMU阈值", "返回"
                                 };
const char *ControlTypeItems[]  = { "控制类型", "直接控制", "PID控制" };
const char *MainScreenItems[]   = { "主屏幕", "大数字显示", "更多信息" };
const char *StoreItems[]        = { "保存设置？", "否", "是" };
const char *SureItems[]         = { "确定吗？", "否", "是" };
const char *BuzzerItems[]       = { "蜂鸣器", "禁用", "启用" };
const char *DefaultTempItems[]  = { "默认温度", "摄氏度" };
const char *SleepTempItems[]    = { "休眠温度", "摄氏度" };
const char *BoostTempItems[]    = { "增强温度", "摄氏度" };
const char *SleepTimerItems[]   = { "休眠定时器", "秒" };
const char *LISthresholdItems[] = { "IMU阈值", "mg" };
const char *OffTimerItems[]     = { "关机定时器", "分钟" };
const char *BoostTimerItems[]   = { "增强定时器", "秒" };
const char *DeleteMessage[]     = { "警告", "你不能", "删除你的", "最后一个烙铁头！" };
const char *MaxTipMessage[]     = { "警告", "你已达到", "最大数量", "的烙铁头！" };

// 引脚变化中断相关变量
volatile uint8_t  a0, b0, c0, d0;
volatile bool     ab0;
volatile int      count, countMin, countMax, countStep;
volatile bool     handleMoved;

// 温度控制相关变量
uint16_t  SetTemp, ShowTemp, gap, Step;
double    Input, Output, Setpoint, RawTemp, CurrentTemp, ChipTemp;

// 电压读数相关变量
uint16_t  Vcc, Vin;

// 状态变量
bool      inSleepMode = false;
bool      inOffMode   = false;
bool      inBoostMode = false;
bool      inCalibMode = false;
bool      isWorky     = true;
bool      beepIfWorky = true;
bool      TipIsPresent = true;

// 定时相关变量
uint32_t  sleepmillis;
uint32_t  boostmillis;
uint32_t  buttonmillis;
uint8_t   goneMinutes;
uint8_t   goneSeconds;
uint8_t   SensorCounter = 255;

// 指定变量指针和初始PID调谐参数
PID ctrl(&Input, &Output, &Setpoint, aggKp, aggKi, aggKd, REVERSE);

// 根据OLED控制器设置u8g对象
#if defined (SSD1306)
U8GLIB_SSD1306_128X64 u8g(U8G_I2C_OPT_DEV_0 | U8G_I2C_OPT_NO_ACK | U8G_I2C_OPT_FAST);
#elif defined (SH1106)
U8GLIB_SH1106_128X64 u8g(U8G_I2C_OPT_FAST | U8G_I2C_OPT_NO_ACK);
#elif defined (SH1107)
U8G2_SH1107_64X128_1_HW_I2C u8g(U8G2_R1, A3);
#else
#error 错误的OLED控制器类型！
#endif

// 用于drawStr的缓冲区
char F_Buffer[20];

// LIS2DW12传感器对象
LIS2DW12Sensor Accelero(&Wire, LIS2DW12_I2C_ADD_L);
LIS2DW12_Event_Status_t state;
float lastLISTmp = 0;
float newLISTmp = 0;
uint8_t LISTmpTime = 0;


void setup() {
  // 设置引脚模式
  pinMode(SENSOR_PIN,   INPUT);
  pinMode(VIN_PIN,      INPUT);
  pinMode(BUZZER_PIN,   OUTPUT);
  pinMode(CONTROL_PIN,  OUTPUT);
  pinMode(BUTTON_P_PIN, INPUT_PULLUP);
  pinMode(BUTTON_N_PIN, INPUT_PULLUP);
  pinMode(BUTTON_PIN,   INPUT_PULLUP);
  pinMode(SWITCH_PIN,   INPUT_PULLUP);

  analogWrite(CONTROL_PIN, HEATER_OFF); // 关闭加热器
  digitalWrite(BUZZER_PIN, LOW);        // 蜂鸣器不使用时必须为低电平

  // 设置ADC
  ADCSRA |= bit (ADPS0) | bit (ADPS1) | bit (ADPS2);  // 设置ADC预分频器为128
  ADCSRA |= bit (ADIE);                 // 启用ADC中断
  interrupts ();                        // 启用全局中断

  // // 设置旋转编码器的引脚变化中断
  // PCMSK0 = bit (PCINT0);                // 在Pin8上配置引脚变化中断
  // PCICR  = bit (PCIE0);                 // 启用引脚变化中断
  // PCIFR  = bit (PCIF0);                 // 清除中断标志

  // 设置LIS传感器
  Wire.begin();
  Accelero.begin();
  Accelero.Enable_X();
  Accelero.WriteReg(LIS2DW12_CTRL6, 0x04);
  Accelero.WriteReg(LIS2DW12_CTRL1, 0x17);
  Accelero.Set_FIFO_Mode(LIS2DW12_STREAM_MODE);

  // 准备并启动OLED
  u8g.begin();
  //  if      ( u8g.getMode() == U8G_MODE_R3G3B2 )   u8g.setColorIndex(255);
  //  else if ( u8g.getMode() == U8G_MODE_GRAY2BIT ) u8g.setColorIndex(3);
  //  else if ( u8g.getMode() == U8G_MODE_BW )       u8g.setColorIndex(1);
  //  else if ( u8g.getMode() == U8G_MODE_HICOLOR )  u8g.setHiColorByRGB(255,255,255);

  // 从EEPROM获取默认值
  getEEPROM();

  // 读取电源电压（毫伏）
  delay(100);
  Vcc = getVCC(); Vin = getVIN();

  // 读取并设置当前烙铁温度
  SetTemp  = DefaultTemp;
  RawTemp  = denoiseAnalog(SENSOR_PIN);
  ChipTemp = getChipTemp();
  calculateTemp();

  // 如果烙铁温度远低于设定点，则打开加热器
  if ((CurrentTemp + 20) < DefaultTemp) analogWrite(CONTROL_PIN, HEATER_ON);

  // 设置PID输出范围并启动PID
  ctrl.SetOutputLimits(0, 255);
  ctrl.SetMode(AUTOMATIC);

  // 设置初始旋转编码器值
  //a0 = PINB & 1; b0 = PIND >> 7 & 1; ab0 = (a0 == b0);
  a0 = 0;
  b0 = 0;
  setRotary(TEMP_MIN, TEMP_MAX, TEMP_STEP, DefaultTemp);

  // 重置休眠定时器
  sleepmillis = millis();

  lastLISTmp = getLISTemp();

  // 设置完成时长鸣提示
  beep(); beep();
}


void loop() {
  ROTARYCheck();      // 检查旋转编码器（温度/增强设置，进入设置菜单）
  SLEEPCheck();       // 检查并激活/停用休眠模式
  SENSORCheck();      // 读取烙铁的温度和振动开关
  Thermostat();       // 加热器控制
  MainScreen();       // 更新OLED上的主页面
}




// 检查旋转编码器；相应设置温度、切换增强模式、进入设置菜单
void ROTARYCheck() {
  // 根据旋转编码器值设置工作温度
  SetTemp = getRotary();

  // 检查旋转编码器开关
  uint8_t c = digitalRead(BUTTON_PIN);
  if ( !c && c0 ) {
    beep();
    buttonmillis = millis();
    while ( (!digitalRead(BUTTON_PIN)) && ((millis() - buttonmillis) < 500) );
    if ((millis() - buttonmillis) >= 500) SetupScreen();
    else {
      inBoostMode = !inBoostMode;
      if (inBoostMode) boostmillis = millis();
      handleMoved = true;
    }
  }
  c0 = c;

  // 检查增强模式下的定时器
  if (inBoostMode && timeOfBoost) {
    goneSeconds = (millis() - boostmillis) / 1000;
    if (goneSeconds >= timeOfBoost) {
      inBoostMode = false;              // 停止增强模式
      beep();                           // 增强模式结束时蜂鸣提示
      beepIfWorky = true;               // 达到工作温度时再次蜂鸣
    }
  }
}


// 检查并激活/停用休眠模式
void SLEEPCheck() {
  if (handleMoved) {                    // 如果手柄被移动
    if (inSleepMode) {                  // 是否在休眠或关机模式？
      if ((CurrentTemp + 20) < SetTemp) // 如果温度远低于设定点
        analogWrite(CONTROL_PIN, HEATER_ON);    // 立即启动加热器
      beep();                           // 唤醒时蜂鸣提示
      beepIfWorky = true;               // 达到工作温度时再次蜂鸣
    }
    handleMoved = false;                // 重置手柄移动标志
    inSleepMode = false;                // 重置休眠标志
    inOffMode   = false;                // 重置关机标志
    sleepmillis = millis();             // 重置休眠定时器
  }

  // 检查自手柄移动后经过的时间
  goneSeconds = (millis() - sleepmillis) / 1000;
  if ( (!inSleepMode) && (time2sleep > 0) && (goneSeconds >= time2sleep) ) {
    inSleepMode = true;
    beep();
  }
  if ( (!inOffMode)   && (time2off   > 0) && ((goneSeconds / 60) >= time2off  ) ) {
    inOffMode   = true;
    beep();
  }
}


// 读取温度、振动开关和电源电压
void SENSORCheck() {
  uint16_t sampleNum = 0;
  Accelero.Get_FIFO_Num_Samples(&sampleNum);
  if (sampleNum == 32) {
    int16_t accelerometer[3][32];
    for (int i = 0; i < 32; i++) {
      int32_t accelerometer_temp[3];
      Accelero.Get_X_Axes(accelerometer_temp);
      accelerometer[0][i] = accelerometer_temp[0];
      accelerometer[1][i] = accelerometer_temp[1];
      accelerometer[2][i] = accelerometer_temp[2];
    }
    if (variance(accelerometer[0]) > LISthreshold) {
      handleMoved = true;
    } else if (variance(accelerometer[1]) > LISthreshold) {
      handleMoved = true;
    } else if (variance(accelerometer[2]) > LISthreshold) {
      handleMoved = true;
    }
  }
  analogWrite(CONTROL_PIN, HEATER_OFF);       // 关闭加热器以便测量温度
  delayMicroseconds(TIME2SETTLE);             // 等待电压稳定

  double temp = denoiseAnalog(SENSOR_PIN);    // 读取温度的ADC值

  if (! SensorCounter--) Vin = getVIN();      // 定期获取输入电压

  analogWrite(CONTROL_PIN, HEATER_PWM);       // 重新打开加热器

  RawTemp += (temp - RawTemp) * SMOOTHIE;     // 稳定ADC温度读数
  calculateTemp();                            // 计算实际温度值

  // 当温度接近设定点时稳定显示的温度
  if ((ShowTemp != Setpoint) || (abs(ShowTemp - CurrentTemp) > 5)) ShowTemp = CurrentTemp;
  if (abs(ShowTemp - Setpoint) <= 1) ShowTemp = Setpoint;

  // 如果温度在工作范围内设置状态变量；如果刚达到工作温度则蜂鸣提示
  gap = abs(SetTemp - CurrentTemp);
  if (gap < 5) {
    if (!isWorky && beepIfWorky) beep();
    isWorky = true;
    beepIfWorky = false;
  }
  else isWorky = false;

  // 检查烙铁头是否存在或当前插入
  if (ShowTemp > 500) TipIsPresent = false;   // 烙铁头被移除？
  if (!TipIsPresent && (ShowTemp < 500)) {    // 新烙铁头插入？
    analogWrite(CONTROL_PIN, HEATER_OFF);     // 关闭加热器
    beep();                                   // 信息提示蜂鸣
    TipIsPresent = true;                      // 现在烙铁头存在
    ChangeTipScreen();                        // 显示烙铁头选择屏幕
    updateEEPROM();                           // 更新EEPROM中的设置
    handleMoved = true;                       // 重置所有定时器
    RawTemp  = denoiseAnalog(SENSOR_PIN);     // 重新启动温度平滑算法
    c0 = LOW;                                 // 开关必须释放
    setRotary(TEMP_MIN, TEMP_MAX, TEMP_STEP, SetTemp);  // 重置旋转编码器
  }
}


// 根据ADC读数和校准值计算实际温度值
void calculateTemp() {
  if      (RawTemp < 200) CurrentTemp = map (RawTemp,   0, 200,                     21, CalTemp[CurrentTip][0]);
  else if (RawTemp < 280) CurrentTemp = map (RawTemp, 200, 280, CalTemp[CurrentTip][0], CalTemp[CurrentTip][1]);
  else                    CurrentTemp = map (RawTemp, 280, 360, CalTemp[CurrentTip][1], CalTemp[CurrentTip][2]);
}


// 控制加热器
void Thermostat() {
  // 根据当前工作模式定义设定点
  if      (inOffMode)   Setpoint = 0;
  else if (inSleepMode) Setpoint = SleepTemp;
  else if (inBoostMode) Setpoint = SetTemp + BoostTemp;
  else                  Setpoint = SetTemp;

  // 控制加热器（PID或直接控制）
  gap = abs(Setpoint - CurrentTemp);
  if (PIDenable) {
    Input = CurrentTemp;
    if (gap < 30) ctrl.SetTunings(consKp, consKi, consKd);
    else ctrl.SetTunings(aggKp, aggKi, aggKd);
    ctrl.Compute();
  } else {
    // 如果当前温度低于设定点则打开加热器
    if ((CurrentTemp + 0.5) < Setpoint) Output = 0; else Output = 255;
  }
  analogWrite(CONTROL_PIN, HEATER_PWM);     // 设置加热器PWM
}


// 在蜂鸣器上创建短促的蜂鸣声
void beep() {
  if (beepEnable) {
    for (uint8_t i = 0; i < 255; i++) {
      digitalWrite(BUZZER_PIN, HIGH);
      delayMicroseconds(125);
      digitalWrite(BUZZER_PIN, LOW);
      delayMicroseconds(125);
    }
  }
}


// 设置旋转编码器的起始值
void setRotary(int rmin, int rmax, int rstep, int rvalue) {
  countMin  = rmin << ROTARY_TYPE;
  countMax  = rmax << ROTARY_TYPE;
  countStep = rstep;
  count     = rvalue << ROTARY_TYPE;
}


// 读取当前旋转编码器值
int getRotary() {
  Button_loop();
  return (count >> ROTARY_TYPE);
}


// 从EEPROM读取用户设置；如果EEPROM值无效，则写入默认值
void getEEPROM() {
  uint16_t identifier = (EEPROM.read(0) << 8) | EEPROM.read(1);
  if (identifier == EEPROM_IDENT) {
    DefaultTemp = (EEPROM.read(2) << 8) | EEPROM.read(3);
    SleepTemp   = (EEPROM.read(4) << 8) | EEPROM.read(5);
    BoostTemp   =  EEPROM.read(6);
    time2sleep  =  EEPROM.read(7);
    time2off    =  EEPROM.read(8);
    timeOfBoost =  EEPROM.read(9);
    MainScrType =  EEPROM.read(10);
    PIDenable   =  EEPROM.read(11);
    beepEnable  =  EEPROM.read(12);
    CurrentTip  =  EEPROM.read(13);
    NumberOfTips = EEPROM.read(14);
    LISthreshold = EEPROM.read(15);


    uint8_t i, j;
    uint16_t counter = 16;
    for (i = 0; i < NumberOfTips; i++) {
      for (j = 0; j < TIPNAMELENGTH; j++) {
        TipName[i][j] = EEPROM.read(counter++);
      }
      for (j = 0; j < 4; j++) {
        CalTemp[i][j]  = EEPROM.read(counter++) << 8;
        CalTemp[i][j] |= EEPROM.read(counter++);
      }
    }
  }
  else {
    EEPROM.update(0, EEPROM_IDENT >> 8); EEPROM.update(1, EEPROM_IDENT & 0xFF);
    updateEEPROM();
  }
}


// 使用更新功能将用户设置写入EEPROM以最小化写入周期
void updateEEPROM() {
  EEPROM.update( 2, DefaultTemp >> 8);
  EEPROM.update( 3, DefaultTemp & 0xFF);
  EEPROM.update( 4, SleepTemp >> 8);
  EEPROM.update( 5, SleepTemp & 0xFF);
  EEPROM.update( 6, BoostTemp);
  EEPROM.update( 7, time2sleep);
  EEPROM.update( 8, time2off);
  EEPROM.update( 9, timeOfBoost);
  EEPROM.update(10, MainScrType);
  EEPROM.update(11, PIDenable);
  EEPROM.update(12, beepEnable);
  EEPROM.update(13, CurrentTip);
  EEPROM.update(14, NumberOfTips);
  EEPROM.update(15, LISthreshold);

  uint8_t i, j;
  uint16_t counter = 16;
  for (i = 0; i < NumberOfTips; i++) {
    for (j = 0; j < TIPNAMELENGTH; j++) EEPROM.update(counter++, TipName[i][j]);
    for (j = 0; j < 4; j++) {
      EEPROM.update(counter++, CalTemp[i][j] >> 8);
      EEPROM.update(counter++, CalTemp[i][j] & 0xFF);
    }
  }
}


// 绘制主屏幕
void MainScreen() {
  u8g.firstPage();
  do {
    // 绘制设定点温度
    u8g.setFont(u8g2_font_9x15_tf);
    u8g.setFontPosTop();
    u8g.drawStr( 0, 0,  "SET:");
    u8g.setCursor(40, 0);
    u8g.print(Setpoint, 0);
    //    int32_t accelerometer[3];
    //    Accelero.Get_X_Axes(accelerometer);
    //    u8g.setCursor(0, 0);
    //    u8g.print(accelerometer[0], DEC);

    // 绘制加热器状态
    u8g.setCursor(83, 0);
    if (ShowTemp > 500)    u8g.print(F("ERROR"));
    else if (inOffMode)    u8g.print(F("  OFF"));
    else if (inSleepMode)  u8g.print(F("SLEEP"));
    else if (inBoostMode)  u8g.print(F("BOOST"));
    else if (isWorky)      u8g.print(F("WORKY"));
    else if (Output < 180) u8g.print(F(" HEAT"));
    else                   u8g.print(F(" HOLD"));

    // 其余部分取决于主屏幕类型
    if (MainScrType) {
      // 绘制当前烙铁头和输入电压
      float fVin = (float)Vin / 1000;     // 将毫伏转换为伏特
      newLISTmp = newLISTmp + 0.01 * getLISTemp();
      LISTmpTime++;
      if (LISTmpTime >= 100) {
        lastLISTmp = newLISTmp;
        newLISTmp = 0;
        LISTmpTime = 0;
      }
      u8g.setCursor( 0, 52); u8g.print(lastLISTmp, 1); u8g.print(F("C"));
      u8g.setCursor(83, 52); u8g.print(fVin, 1); u8g.print(F("V"));
      // 绘制当前温度
      u8g.setFont(u8g2_font_freedoomr25_tn);
      u8g.setFontPosTop();
      u8g.setCursor(37, 22);
      if (ShowTemp > 500) u8g.print(F("000")); else u8g.print(ShowTemp);
    } else {
      // 以大数字绘制当前温度
      u8g.setFont(u8g2_font_fub42_tn);
      u8g.setFontPosTop();
      u8g.setCursor(15, 20);
      if (ShowTemp > 500) u8g.print(F("000")); else u8g.print(ShowTemp);
    }
  } while (u8g.nextPage());
}


// 设置屏幕
void SetupScreen() {
  analogWrite(CONTROL_PIN, HEATER_OFF);      // 关闭加热器
  beep();
  uint16_t SaveSetTemp = SetTemp;
  uint8_t selection = 0;
  bool repeat = true;

  while (repeat) {
    selection = MenuScreen(SetupItems, sizeof(SetupItems), selection);
    switch (selection) {
      case 0:   TipScreen(); repeat = false; break;
      case 1:   TempScreen(); break;
      case 2:   TimerScreen(); break;
      case 3:   PIDenable = MenuScreen(ControlTypeItems, sizeof(ControlTypeItems), PIDenable); break;
      case 4:   MainScrType = MenuScreen(MainScreenItems, sizeof(MainScreenItems), MainScrType); break;
      case 5:   beepEnable = MenuScreen(BuzzerItems, sizeof(BuzzerItems), beepEnable); break;
      case 6:   InfoScreen(); break;
      default:  repeat = false; break;
    }
  }
  updateEEPROM();
  handleMoved = true;
  SetTemp = SaveSetTemp;
  setRotary(TEMP_MIN, TEMP_MAX, TEMP_STEP, SetTemp);
}


// 烙铁头设置屏幕
void TipScreen() {
  uint8_t selection = 0;
  bool repeat = true;
  while (repeat) {
    selection = MenuScreen(TipItems, sizeof(TipItems), selection);
    switch (selection) {
      case 0:   ChangeTipScreen();   break;
      case 1:   CalibrationScreen(); break;
      case 2:   InputNameScreen();   break;
      case 3:   DeleteTipScreen();   break;
      case 4:   AddTipScreen();      break;
      default:  repeat = false;      break;
    }
  }
}


// 温度设置屏幕
void TempScreen() {
  uint8_t selection = 0;
  bool repeat = true;
  while (repeat) {
    selection = MenuScreen(TempItems, sizeof(TempItems), selection);
    switch (selection) {
      case 0:   setRotary(TEMP_MIN, TEMP_MAX, TEMP_STEP, DefaultTemp);
        DefaultTemp = InputScreen(DefaultTempItems); break;
      case 1:   setRotary(20, 200, TEMP_STEP, SleepTemp);
        SleepTemp = InputScreen(SleepTempItems); break;
      case 2:   setRotary(10, 100, TEMP_STEP, BoostTemp);
        BoostTemp = InputScreen(BoostTempItems); break;
      default:  repeat = false; break;
    }
  }
}


// 定时器设置屏幕
void TimerScreen() {
  uint8_t selection = 0;
  bool repeat = true;
  while (repeat) {
    selection = MenuScreen(TimerItems, sizeof(TimerItems), selection);
    switch (selection) {
      case 0:   setRotary(0, 600, 10, time2sleep);
        time2sleep = InputScreen(SleepTimerItems); break;
      case 1:   setRotary(0, 60, 5, time2off);
        time2off = InputScreen(OffTimerItems); break;
case 2:   setRotary(0, 180, 10, timeOfBoost);
        timeOfBoost = InputScreen(BoostTimerItems); break;
      case 3:   setRotary(0, 50, 1, LISthreshold);
        LISthreshold = InputScreen(LISthresholdItems); break;
      default:  repeat = false; break;
    }
  }
}
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

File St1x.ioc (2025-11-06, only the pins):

Mcu.UserName=STM32F103CBTx
PA0-WKUP.GPIO_Label=INT1
PA0-WKUP.Signal=GPXTI0
PA1.GPIO_Label=TEMP_CON1
PA1.Signal=S_TIM2_CH2
PA10.Signal=USART1_RX
PA11.Signal=USB_DM
PA12.Signal=USB_DP
PA13.Signal=SYS_JTMS-SWDIO
PA14.Signal=SYS_JTCK-SWCLK
PA15.GPIO_Label=OLED_PW_EN
PA15.Signal=GPIO_Output
PA2.GPIO_Label=USB_VOLT_DET
PA2.Signal=ADCx_IN2
PA3.Signal=S_TIM2_CH4
PA5.GPIO_Label=KEY_DOWN
PA5.Signal=GPXTI5
PA6.GPIO_Label=KEY_MODE
PA6.Signal=GPXTI6
PA7.GPIO_Label=KEY_UP
PA7.Signal=GPXTI7
PA8.GPIO_Label=OLED_DC
PA8.Signal=GPIO_Output
PA9.Signal=USART1_TX
PB0.GPIO_Label=Buzzer
PB0.Signal=GPIO_Output
PB1.Signal=ADCx_IN9
PB10.GPIO_Label=OLED_IM
PB10.Signal=GPIO_Output
PB11.GPIO_Label=G_CS
PB11.Signal=GPIO_Output
PB12.GPIO_Label=OLED_CS
PB12.Signal=GPIO_Output
PB13.GPIO_Label=SPI2_SCK
PB13.Signal=SPI2_SCK
PB14.GPIO_Label=SPI2_MISO
PB14.Signal=SPI2_MISO
PB15.GPIO_Label=SPI2_MOSI
PB15.Signal=SPI2_MOSI
PB3.GPIO_Label=OLED_Reset
PB3.Signal=GPIO_Output
PB4.GPIO_Label=LED_BLUE
PB4.Signal=S_TIM3_CH1
PB5.GPIO_Label=LED_RGB
PB5.Signal=GPIO_Output
PB6.Signal=I2C1_SCL
PB7.Signal=I2C1_SDA
PB8.GPIO_Label=LED_GREEN
PB8.Signal=S_TIM4_CH3
PB9.GPIO_Label=LED_RED
PB9.Signal=S_TIM4_CH4
PD0-OSC_IN.Signal=RCC_OSC_IN
PD1-OSC_OUT.Signal=RCC_OSC_OUT

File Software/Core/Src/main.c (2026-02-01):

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
/* Includes ------------------------------------------------------------------*/
#include "main.h"
#include "adc.h"
#include "dma.h"
#include "i2c.h"
#include "spi.h"
#include "tim.h"
#include "usart.h"
#include "usb_device.h"
#include "gpio.h"

/* USER CODE BEGIN Includes */
#include <math.h>
#include "u8g2.h"
#include "u8g2_oled.h"
#include "St1xADC.h"
#include "bmp.h"
#include "lis2dw12.h"
#include "St1xPID.h"
#include "ws2812.h"
#include "St1xMenu.h"
#include "St1xKey.h"
#include "St1xStatic.h"
#include "St1xCalibrationSystem.h"
#include "Buzzer.h"
#include "St1xSystemManager.h"

// 声明外部变量
extern uint8_t heating_status;

// 环境温度感知系统相关变量声明
extern uint32_t system_start_time;
extern uint32_t last_heating_time;

// 校准系统所需的外部函数声明
extern float getCalibrationTemperature(void);
extern uint8_t isUSBVoltageSufficient(void);
extern void StopCalibrationHeating(void);
extern void StartCalibrationHeating(void);
/* USER CODE END Includes */

/* USER CODE BEGIN PD */
// 显示更新间隔(ms)
#define DISPLAY_UPDATE_INTERVAL 100
// 静置检查间隔(ms)
#define STANDBY_CHECK_INTERVAL 1000
// 菜单进入延迟(ms)
#define MENU_ENTER_DELAY 200
// 温度显示变化阈值(°C)
#define TEMP_DISPLAY_THRESHOLD 0.5f
/* USER CODE END PD */


/* USER CODE BEGIN PV */
// 定义u8g2全局变量
u8g2_t u8g2;

// 菜单活动状态变量
uint8_t menu_active = 0;

// OLED更新计时
uint32_t last_oled_update = 0;

// 调试显示标志
uint8_t debug_display_enabled = 0;  // 默认关闭调试显示 0关闭 1开启

// 使用系统管理模块中定义的系统模式
extern SystemMode current_system_mode;

// 系统状态标志
uint8_t timer_started = 0;  // 定时器启动标志
uint32_t last_standby_check = 0;  // 上次静置检查时间
float last_displayed_temp = 0;  // 上次显示的温度值
uint32_t menu_enter_delay = 0;  // 菜单进入延迟计时
/* USER CODE END PV */

void SystemClock_Config(void);
/* USER CODE BEGIN PFP */

// 系统初始化函数（保留硬件相关初始化）
void System_Init(void);
void LED_Init(void);
void Display_Init(void);
void ADC_Init(void);
void Timer_Init(void);

/* USER CODE END PFP */

/* USER CODE BEGIN 0 */

//===========================
// 中断回调函数
//===========================

/**
 * @brief TIM2定时器中断回调函数
 */
void HAL_TIM_PeriodElapsedCallback(TIM_HandleTypeDef *htim) {
    if (htim->Instance == TIM2) {
        heatingControlTimerCallback();  // 调用加热控制逻辑
    }
}

/* USER CODE END 0 */

/**
  * @brief  The application entry point.
  * @retval int
  */
int main(void)
{

  /* MCU Configuration--------------------------------------------------------*/

  /* Reset of all peripherals, Initializes the Flash interface and the Systick. */
  HAL_Init();

  /* Configure the system clock */
  SystemClock_Config();

  /* Initialize all configured peripherals */
  MX_GPIO_Init();
  MX_DMA_Init();
  MX_ADC1_Init();
  MX_SPI2_Init();
  MX_TIM2_Init();
  MX_TIM3_Init();
  MX_USART1_UART_Init();
  MX_TIM4_Init();
  MX_TIM1_Init();
  MX_I2C1_Init();
  MX_USB_DEVICE_Init();
  /* USER CODE BEGIN 2 */
    // 系统初始化
    System_Init();
  /* USER CODE END 2 */

  /* Infinite loop */
  /* USER CODE BEGIN WHILE */
  while (1)
  {
    /* USER CODE END WHILE */

    /* USER CODE BEGIN 3 */
    uint32_t current_time = HAL_GetTick();
    
    // 系统状态监控（始终运行）
    systemStatusMonitor();
    
    // 定期检查静置状态
    if ((current_time - last_standby_check) >= STANDBY_CHECK_INTERVAL) {
        St1xStatic_DisplayData(NULL); // 检查静置状态
        last_standby_check = current_time;
    }
    
    // 静置状态下的屏幕和LED控制
    St1xStatic_TimerCallback();
    
    // 根据当前系统模式处理不同的逻辑
    SystemManager_ModeHandler(current_time);
    
    // 更新蜂鸣器状态机
//    buzzerBeep_update();
    
    // 更新启动音状态机
//    buzzerStartupBeep_update();
    
    // 各模块有独立的定时刷新机制，无需主循环延时
  }
  /* USER CODE END 3 */
}

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
/* USER CODE BEGIN 4 */

//===========================
// 系统初始化函数
//===========================

/**
 * @brief 系统初始化 - 负责硬件外设的初始化
 */
void System_Init(void) {
    // 记录系统启动时间
    system_start_time = HAL_GetTick();
    
    LED_Init();
    Display_Init();
    ADC_Init();
    Timer_Init();
//    buzzer_init();  // 初始化蜂鸣器状态机
//    buzzerStartupBeep();            // 播放开机启动音
//    buzzerRadarBeep();             // 播放渐进启动音
    SystemManager_AppModulesInit();  // 应用模块初始化已移动到系统管理模块
}

/**
 * @brief LED初始化
 */
void LED_Init(void) {
    HAL_TIM_PWM_Start(&htim4, TIM_CHANNEL_3);
    HAL_TIM_PWM_Start(&htim4, TIM_CHANNEL_4);
    HAL_TIM_PWM_Start(&htim3, TIM_CHANNEL_1);
    __HAL_TIM_SetCompare(&htim4, TIM_CHANNEL_3, 0);  // 红色LED
    __HAL_TIM_SetCompare(&htim4, TIM_CHANNEL_4, 0);  // 绿色LED
    __HAL_TIM_SetCompare(&htim3, TIM_CHANNEL_1, 0);  // 蓝色LED
}

/**
 * @brief 显示初始化
 */
void Display_Init(void) {
    spi_oled_Init(&u8g2);           // 初始化OLED
    u8g2_DrawXBMP(&u8g2,0,0,128,80,Logo);  // 显示开机LOGO
    u8g2_SendBuffer(&u8g2);
    HAL_Delay(1000);                // 显示开机LOGO 1秒钟
    u8g2_ClearBuffer(&u8g2);
}

/**
 * @brief ADC初始化
 */
void ADC_Init(void) {
    HAL_ADCEx_Calibration_Start(&hadc1);  // ADC自动校准
}

/**
 * @brief 定时器初始化
 */
void Timer_Init(void) {
    // 暂时不启动TIM2中断，避免过早启动PID控制
    // 首次显示更新完成后，在System_NormalModeHandler中再启动定时器
}













/* USER CODE END 4 */
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


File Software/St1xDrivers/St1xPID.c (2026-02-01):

/**
 * @file    St1xPID.c
 * @brief   T12烙铁控制器 - 温度控制实现
 * @author  Leon Red
 * @date    2023-02-13
 */

#include "St1xPID.h"
#include "St1xADC.h"
#include "St1xFocusedHeating.h"
#include "adc.h"
#include "tim.h"
#include <math.h>
#include <stdio.h>
#include "St1xCalibrationSystem.h"

// 外部变量声明
extern uint16_t DMA_ADC[3];
extern float target_temperature;
extern uint32_t last_control_time;
extern uint32_t heating_start_time;
extern uint8_t heating_control_enabled;
extern float display_filtered_temperature;
extern uint8_t heating_status;
extern uint8_t sampling_phase;
extern uint32_t sample_start_time;
extern uint16_t saved_pwm_value;
extern uint32_t initial_heating_end_time;

// PID控制参数
#define PID_CONSERVATIVE_KP 8.0f    // 保守模式比例系数
#define PID_CONSERVATIVE_KI 2.5f    // 保守模式积分系数
#define PID_CONSERVATIVE_KD 12.0f   // 保守模式微分系数
#define CONTROL_INTERVAL 50         // 控制间隔（毫秒）- 每50ms执行一次完整的控制周期
#define FOCUSED_HEATING_TEMP_DIFF 15.0f // 专注加热温度差阈值 - 当目标温度与当前温度差大于15°C时启用专注加热
#define AGGRESSIVE_HEATING_TEMP_DIFF 5.0f // 激进加热温度差阈值 - 温度差大于5°C时使用100%功率加热
#define PID_PRECISION_THRESHOLD 2.0f  // PID精确控制阈值 - 温度差小于2°C时启用精确PID参数

// 冷启动专用参数
#define COLD_START_AGGRESSIVE_KP 15.0f    // 冷启动激进比例系数
#define COLD_START_AGGRESSIVE_KI 0.8f     // 冷启动激进积分系数
#define COLD_START_AGGRESSIVE_KD 8.0f     // 冷启动激进微分系数

// 全局变量
PID_Controller t12_pid = {0.5, 0.01, 1.2, 0.0, 0.0, 0.0, 0};

// 专注加热模式标志（保持兼容性，但实际使用状态机）
uint8_t focused_heating_mode = 0;

// PID温度控制算法
float pidTemperatureControl(float current_temp) {
    uint32_t current_time = HAL_GetTick();
    float dt = (current_time - t12_pid.last_time) / 1000.0f;
    if (dt <= 0) dt = 0.01f;
    
    float error = t12_pid.setpoint - current_temp;
    
    // 冷启动模式检查 - 使用更激进的加热策略
    extern uint8_t isColdStartMode(void);
    if (isColdStartMode() && error > 20.0f) {
        // 冷启动模式下，温度差大于20°C时使用100%功率加热
        t12_pid.last_time = current_time;
        return 100.0f;
    }
    
    // 专注加热模式检查 - 使用状态机管理
    if (heating_status && heating_control_enabled && error > FOCUSED_HEATING_TEMP_DIFF) {
        // 使用状态机检查是否需要专注加热
        if (FocusedHeating_Update(current_time, current_temp, t12_pid.setpoint)) {
            focused_heating_mode = 1; // 保持兼容性
            t12_pid.last_time = current_time;
            return 100.0f;
        } else {
            focused_heating_mode = 0; // 专注加热完成或不需要
        }
    }
    
    // 激进加热模式
    if (error > AGGRESSIVE_HEATING_TEMP_DIFF && !focused_heating_mode) {
        t12_pid.last_time = current_time;
        return 100.0f;
    }
    
    if (error < -AGGRESSIVE_HEATING_TEMP_DIFF) {
        t12_pid.last_time = current_time;
        return 0.0f;
    }
    
    // 精确PID模式 - 根据冷启动状态选择参数
    if (fabs(error) < PID_PRECISION_THRESHOLD) {
        if (isColdStartMode()) {
            t12_pid.kp = COLD_START_AGGRESSIVE_KP * 0.6f;
            t12_pid.ki = COLD_START_AGGRESSIVE_KI * 1.5f;
            t12_pid.kd = COLD_START_AGGRESSIVE_KD * 1.2f;
        } else {
            t12_pid.kp = PID_CONSERVATIVE_KP * 0.6f;
            t12_pid.ki = PID_CONSERVATIVE_KI * 1.5f;
            t12_pid.kd = PID_CONSERVATIVE_KD * 1.2f;
        }
    } else {
        if (isColdStartMode()) {
            t12_pid.kp = COLD_START_AGGRESSIVE_KP;
            t12_pid.ki = COLD_START_AGGRESSIVE_KI;
            t12_pid.kd = COLD_START_AGGRESSIVE_KD;
        } else {
            t12_pid.kp = PID_CONSERVATIVE_KP;
            t12_pid.ki = PID_CONSERVATIVE_KI;
            t12_pid.kd = PID_CONSERVATIVE_KD;
        }
    }
    
    // PID计算
    float proportional = t12_pid.kp * error;
    t12_pid.integral += error * dt;
    
    // 智能积分衰减
    float integral_decay_factor = (fabs(error) < 5.0f) ? 0.95f : (fabs(error) < 10.0f) ? 0.9f : 0.8f;
    t12_pid.integral *= integral_decay_factor;
    
    // 积分限幅
    if (t12_pid.integral > 20) t12_pid.integral = 20;
    if (t12_pid.integral < -20) t12_pid.integral = -20;
    
    float integral = t12_pid.ki * t12_pid.integral;
    float derivative = t12_pid.kd * (error - t12_pid.prev_error) / dt;
    float output = proportional + integral + derivative;
    
    // 输出限幅
    if (output > 100.0) output = 100.0;
    if (output < 0.0) output = 0.0;
    
    t12_pid.prev_error = error;
    t12_pid.last_time = current_time;
    
    return output;
}

// 设置目标温度
void setT12Temperature(float temperature) {
    t12_pid.setpoint = temperature;
    t12_pid.integral = 0.0;
    t12_pid.prev_error = 0.0;
    t12_pid.last_time = HAL_GetTick();
}

// 获取PID参数
float getPID_Kp(void) { return t12_pid.kp; }
float getPID_Ki(void) { return t12_pid.ki; }
float getPID_Kd(void) { return t12_pid.kd; }

// 启动/停止温度控制定时器
void startHeatingControlTimer(void) {
    heating_control_enabled = 1;
    HAL_TIM_Base_Start_IT(&htim2);
}

void stopHeatingControlTimer(void) {
    heating_control_enabled = 0;
    HAL_TIM_Base_Stop_IT(&htim2);
}
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

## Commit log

2025-10-20 添加LOGO以及删除不必要的文件
2025-10-21 添加PID控制，还需要继续优化
2025-11-01 温度控制，移动平均滤波
    增加温度控制，可以使用UP&DOWN按键控制温度，MODE按键按一次加热再按一次停止加热。增加了ADC移动平均滤波
    [St1x.PrjPcb, St1x.SchDoc]
2025-11-02 增加电压限制发热
    [St1x.SchDoc]
2025-11-03 优化屏幕显示，修改ADC采样以及PID等
    PID控制更加智能化，当低于30度时直接加热3秒不做其它操作，3秒之后再检当前的温度，温度没有接近目标温度继续加热，直到接近目标温度
    [OPA.PrjPcb, OPA_T12.SchDoc, ST1X.DSN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]
2025-11-03 修正T12烙铁头热电偶的参数
2025-11-06 更新目录结构
2025-11-06 独立按键以及菜单模块
2025-11-06 添加6轴传感器"Mark"
2025-11-06 添加6轴传感器实现静置30分钟无动作时进入待机状态
2025-11-07 添加烙铁头校准系统（PID暂时没调用）
2025-11-08 修复若干问题
    1、修复校准界面杂乱的问题
    2、修复开机后需要按2次按键才开始加热的问题
    3、修复开机错误显示加热状态显示的问题
    4、修复设置温度不能马上生效的问题
    5、修复初始化的问题
    [St1xADC.c, St1xADC.h, St1xCalibrationSystem.c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]
2025-11-08 优化显示效果
2025-11-09 添加灯效
2025-11-09 校准系统的配置使用抽象层同步主系统参数
2025-11-09 芯片内部温度
2025-11-10 代码优化
2025-11-14 修复PID不工作
2025-11-16 修复校准完成后恢复进入前状态
2025-11-16 精简校准代码量
2025-11-16 进入传感器数据显示界面时屏幕亮度变暗
2025-11-19 修正校准系统PID失控问题
2025-11-20 修复ADC与蜂鸣器
    修复蜂鸣器频率声音错误，优化ADC因为环境温度变化影响发热不正常。
    [St1x.SchDoc]
2025-11-21 独立专注加热模块
2026-02-01 功能齐全，但UI差强人意！

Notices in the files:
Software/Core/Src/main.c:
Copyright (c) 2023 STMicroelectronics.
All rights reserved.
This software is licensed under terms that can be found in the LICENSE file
